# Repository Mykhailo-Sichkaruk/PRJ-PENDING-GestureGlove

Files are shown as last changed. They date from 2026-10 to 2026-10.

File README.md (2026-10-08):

# Gesture Glove — SMVIT 2026–2027

Team: **Mykhailo Sichkaruk (ST033)** and **[Yaroslav Marochok](https://github.com/ymarochok) (ST029)**.
Our goal is to complete the SMVIT semester project. The assigned team PRJ number is pending.
This is an independent repository created from the teacher's KNIFE/STHDF template.
GitHub: [PRJ-PENDING-GestureGlove](https://github.com/Mykhailo-Sichkaruk/PRJ-PENDING-GestureGlove).

## Start here

- [Team project and course structure](content/docs/sk/sthdf/PRJ-PENDING-GestureGlove/index.md)
- Individual work: [Mykhailo](content/docs/sk/sthdf/ST-033-SichkarukMykhailo/index.md), [Yaroslav](content/docs/sk/sthdf/ST-029-MarochokYaroslav/index.md)
- [Development setup, Arch graphics and MCP](docs/development.md)
- [Project decisions and AI handoff](docs/project-context.md)
- [Template provenance and submission questions](docs/template-provenance.md)
- [Original idea](hardware/reference/glove_smvit.pdf)
- [Existing CAD examples](examples/poc/README.md) — tooling PoCs, not validated device designs

## Development

Install Nix with flakes enabled. From this checkout:

```sh
nix develop
# Optional automatic shell entry, if direnv is installed and hooked into your shell:
direnv allow
```

Open the editable examples:

```sh
nix run .#freecad -- examples/poc/cad/glove-poc.FCStd
nix run .#eeschema -- examples/poc/electronics/glove/gesture-glove-v2.kicad_sch
nix run .#fritzing -- examples/poc/electronics/fritzing/gesture-glove.fzz
```

Documentation only (no CAD downloads):

```sh
nix develop .#docs
npm ci --prefix publishing/docusaurus
make build
make serve
```

Write course material in `content/docs/`; the copy under `publishing/docusaurus/docs/` is generated.
CI builds the site and saves an artifact; it does not publish or submit it to the teacher.
The inherited npm dependency lock currently reports audit findings; see [validation notes](docs/validation.md).

## Team workflow

Use a short feature branch, commit source files, and review through a pull request.
Yaroslav can clone the public repository now. Until collaborator access is granted, use a personal fork for pushes and open PRs from it.
Agree who edits a binary `.FCStd` or `.fzz` before starting: Git cannot reliably merge simultaneous edits.
Keep one person editing a KiCad sheet at a time; text-based storage does not guarantee a safe merge.
Record each student's contribution in their own ST section, with links to commits/results.
Keep course rosters, meeting access details, tokens, machine-specific settings and CAD caches in ignored `.local/`.

The toolchain targets x86_64 Linux on NixOS or another distribution with Nix.
Actual Arch GUI acceptance remains a teammate check; there is no dependency on Codex for manual development.

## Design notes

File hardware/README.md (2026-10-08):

# Hardware

`reference/glove_smvit.pdf` is the original project proposal.
`parts/fritzing/` contains reusable part bundles. Keep the Adafruit license with its part.
The current models live in `examples/poc/`. Final component selection, battery/power design,
pin allocation, enclosure dimensions and build verification are pending.

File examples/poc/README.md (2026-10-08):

# Archived tooling proof of concept

These are editable examples, not final course deliverables or fabrication files.

From the repository root:

```sh
nix run .#freecad -- examples/poc/cad/glove-poc.FCStd
nix run .#eeschema -- examples/poc/electronics/glove/gesture-glove-v2.kicad_sch
nix run .#fritzing -- examples/poc/electronics/fritzing/gesture-glove.fzz
```

The v2 KiCad schematic is the preferred electrical example. Original drafts remain here for reference.
Do not order a PCB or connect a battery from these conceptual examples.
Generators require an explicit `--replace-generated` option before overwriting examples.

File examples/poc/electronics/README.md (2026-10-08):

# Gesture glove — electrical prototype, revision 2

Open `glove/gesture-glove-v2.kicad_sch` for the circuit schematic, or
`fritzing/gesture-glove.fzz` in Fritzing's Breadboard view for the physical-looking
wiring diagram. The Fritzing parts and colored wires are separate editable
objects. Its background text is a separate annotation part.

## Read the drawings

- RF1–RF5: DIY resistive flex strips, drawn as variable resistors in KiCad.
- R1–R5: 10 kohm dividers to GND. C1–C5: 100 nF filters across those resistors.
- Each flex signal uses an ADC1-capable ESP32-S3 pin.
- U1: a finished Adafruit Feather ESP32-S3 #5323, with its charger/regulator.
  KiCad shows only the board connections used here. Pin numbers on this module
  symbol are logical interface names; it has no fabrication footprint.
- P1–P5 in Fritzing: one conductive fingertip pad each, with one electrical lead.
  SW1–SW5 in KiCad represent those pads touching the **same palm fabric**.
  They are not five purchased switches or permanently grounded fingertip pads.
- U2: GY-521 / MPU6050. VCC, GND, SCL, SDA and AD0 are connected; AD0 goes to
  GND for address 0x68. INT, XDA and XCL are unused and omitted in KiCad.
- SW6: a slide switch between EN and GND. Closing it disables the Feather
  regulator; it does not disconnect the battery or disable USB charging.
- BT1: a provisional 3.7 V, 500 mAh LiPo, wired to the board's battery socket.
  The external TP4056 listed in the original idea is superseded by the selected
  Feather's onboard charger in this PoC, not connected in parallel with it.

| Finger | Flex ADC / GPIO | Contact input / GPIO |
| --- | --- | --- |
| Thumb | A5 / 8 | A0 / 18 |
| Index | D5 / 5 | A1 / 17 |
| Middle | D6 / 6 | A2 / 16 |
| Ring | D9 / 9 | A3 / 15 |
| Little | D10 / 10 | A4 / 14 |

I2C: SDA = GPIO3, SCL = GPIO4. Enable internal input pull-ups for A0–A4;
contact with the grounded palm gives LOW. These are digital contact inputs,
not capacitive-touch inputs. Matching net labels in KiCad mean connected wires.
Crossing wires without a junction do not imply a connection.

## What is still provisional

This is a wiring proof of concept, not an electrically simulated or physically
tested device. DIY strip resistance and usable ADC range need measurement and
calibration. **GY-521 boards vary: confirm that the purchased variant works with
3.3 V at VCC before using this supply arrangement.** The exact battery lead
polarity and a suitable protected battery also need confirmation. Dimensions,
wire lengths, strain relief and mounting belong to the mechanical assembly.
The custom Fritzing part PCB views are illustrative; do not fabricate from them.

## Validation

`check_glove_connections.py` exports KiCad's netlist and compares its 16 nets
against Fritzing's native wire connections, including the Feather's internal
power/I2C buses. It checks that the five analog and five digital input nets,
power, I2C and EN connections agree. This catches pin-assignment errors that a
clean ERC alone would not catch. Fritzing's own application renders the supplied
breadboard SVG/PNG; KiCad exports the supplied schematic PDF.

## Sources and artwork

- [Original project idea](../glove_smvit.pdf).
- [Adafruit Feather ESP32-S3 pinouts](https://learn.adafruit.com/adafruit-esp32-s3-feather/pinouts).
- [Adafruit Feather board files and pinout PDF](https://github.com/adafruit/Adafruit-Feather-ESP32-S3-PCB).
- [Adafruit's Fritzing Feather part](https://github.com/adafruit/Fritzing-Library/blob/master/parts/Adafruit%20ESP32-S3%20Feather.fzpz),
  author `kattni`, dated 2022-04-12. Source Git blob:
  `1eed87918221c50f0c28b05f24bd90828101c212`.
  Its unmodified `.fzpz` and upstream license are in `fritzing/parts`.
  Generated sketches wrap the existing artwork in named SVG layer groups so
  Fritzing 1.0.6 displays it; geometry and connector IDs are preserved.
- GY-521 part: Fritzing's bundled `InvenSense_MPU6050.fzp`, author KingDarBoja.
- Flex strips, passive parts, pads, battery, switch and annotation graphics:
  simple custom parts generated by this project; indicative appearance/dimensions.
- [Fritzing MCP source](https://github.com/fedoragobrowse-design/fritzing-mcp).
- [Fritzing native part format](https://github.com/fritzing/fritzing-app/wiki/2.1-Part-file-format).
- [Codex project MCP configuration](https://learn.chatgpt.com/docs/extend/mcp).

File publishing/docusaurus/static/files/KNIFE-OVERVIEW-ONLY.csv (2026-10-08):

00.01.Navigations,,List of Knowledge Contributions – KNIFES,,,,,,,,,,,,,,,
,,,,,,,,,,,,,,,,,
ID,Category,Short Title,Status,Type,Priority,Description,Date of Record,"Context, Origin, Why it was initiated?",Technology,SFIA – Level,SFIA – Domain (?),SFIA – Maturity,Related KNIFE,Tags,Potential Outputs,Owner,Comment
K000001,,EA modelovanie a motivácia,hotové,Metodika / Nástroj,🎯,Systém motivácie pomocou lízaniek a spätnej väzby,01.03.2024,"Jedno z prvých TERNO, vzniklo pri návrhu systému motivácie v rámci tímu",,2,Business Analysis / Modelling,Diagrammatic,,,,,
K000002,Verzionanie-sdlc,Git workflow pre EA modely,v procese,Integrácia,🔥,"Multirelease stratégie, LemonTree, merge politiky",04.03.2024,Založené na reálnej potrebe riešiť multirelease workflow pre EA,,3,Configuration Management,Tool-based,,,,,
K000003,Platformy,LibreOffice + Python integrácia,v procese,Vývoj / Integrácia,🔥,Skriptovanie v LO cez Python a venv izolácie,08.03.2024,Reakcia na požiadavku na moderný vývoj v LibreOffice – Python/venv,,3,Software Development,Scriptable,,,,,
K000004,Technologie,Docker pre študentov (K12),plánované,Edukačné,🧠,Zjednodušené návody a obrázky pre začiatočníkov,20.03.2024,Vzniklo ako návrh edukačného materiálu pri tvorbe kurzov pre Docker,,2,DevOps / Infrastructure,Learning-based,,,,,
K000005,RiverOfMyLife,BaZi pre racionálne duše,zaradené,Osobný rozvoj / Algoritmika,💡,Sebapoznanie cez dátum a čas narodenia (BaZi),18.04.2025,Záznam vznikol počas diskusie o TCM a racionálnom prístupe k BaZi,,2,Knowledge Engineering,Exploratory,,,,,
K000006,,Tímová správa práv v Gitea,pripomenúť,Správa / Práva,📌,"Rozdelenie práv podľa tímov, chránené vetvy, PR politiky",08.04.2024,Zaznamenané počas diskusie o Gitea právach a workflow – T002,,3,Configuration Management,Tool-based,,,,,
K000007,,Helper skript na obrázky v Markdown,aktívne,Automatizácia,⚙️,Generovanie obrázkových blokov do .md vrátane URL,17.04.2024,Vzniklo pri návrhu Markdown workflow helpera – súvisiace s T007,,2,General Knowledge Work,Adaptive,,,,,
K000008,,DCMM a DAO – hodnota leadershipu,plánované,Hodnoty / Strategické,🧭,"Sebariadenie, dôvera a samočistiace systémy",04.04.2024,Diskusia o leadership kvalite v rámci strategických tém – T008,,2,Business Analysis / Modelling,Diagrammatic,,,,,
K000009,,LinkedIn post engine – AI automatizácia,koncept,Marketing / AI,🧪,Generovanie postov na LinkedIn z obsahu,10.04.2024,"Myšlienka z praxe na LinkedIn, súvis s T009 a zdieľaním obsahu",,2,General Knowledge Work,Adaptive,,,,,
K000010,,OpenAI klient – vlastná AI komunikácia,začiatok,Vývoj / AI,⚡,Appka s prepojením na OpenAI API a archív komunikácie,13.04.2024,"Začiatok vývoja AI nástroja, súvisí s plánom T018",,2,General Knowledge Work,Adaptive,,,,,
K000011,LO vývoj,Main.xba šablóna pre LO Basic,v backlogu,Šablóny / LO,🧱,Základná štartovacia knižnica makier v LibreOffice,09.04.2024,Téma makier v LibreOffice – samostatný štartovací modul,,2,General Knowledge Work,Adaptive,,,,,
K000012,,EA Workflow Add-In – pokročilé šablóny,v backlogu,EA Add-In,📂,Workflow pre pokročilých analytikov v EA,10.04.2024,Rozšírenie pre EA Add-In v rámci T012,,3,Configuration Management,Tool-based,,,,,
K000013,,ReadOnlyControl v EA – Workflow Add-In,koncept,EA Add-In,🔒,Obmedzenie práv v EA na základe kontextu a roly,10.04.2024,Doplnok k EA Add-In – konkrétne obmedzenia práv (ReadOnly),,3,Configuration Management,Tool-based,,,,,
K000014,,Manažér knižníc pre LO Basic,návrh,LibreOffice / Knižnice,📚,Načítanie a správa knižníc v LO Basic,10.04.2024,Nástroj pre správu LO knižníc – samostatne definovaný,,2,General Knowledge Work,Adaptive,,,,,
K000015,LO Vývoj,LibreOffice Basic → Python migrácia,aktívne,Migrácia / Vývoj,🔁,Konverzia VB makier do Python skriptov,13.04.2024,Migrácia z VB do Python – vzniklo počas T003 a T014,,3,Software Development,Scriptable,,,,,
K000016,,Helper skript pre LO symbolic link,v testovaní,Skriptovanie / LO,🧪,Obnova symbolic linku pre user/scripts/,13.04.2024,Podpora pre vývojové prostredie LO – vzniklo počas T015,,2,General Knowledge Work,Adaptive,,,,,
K000017,,AI-powered TERNO Planner,koncept,Plánovanie / AI,📅,Nástroj na správu a sledovanie TERNA záznamov,16.04.2025,Zaznamenané počas návrhu plánovania TERNA – prehľadový modul,,2,General Knowledge Work,Adaptive,,,,,
K000019,,"BaZi výpočty – algoritmus, hodiny, kalendár",zaradené,Algoritmika / Osobný rozvoj,🧠,"Výpočtový rámec BaZi v Pythone alebo Exceli, denné a hodinové analýzy, poradca",18.04.2025,Rozšírenie T005 – potreba výpočtu BaZi a hodinovej analýzy,,2,Knowledge Engineering,Exploratory,,,,,
K000020,LO Platforma pre komunitu,LibreOffice ako komunitná platforma,koncept,Strategické / Komunitné,🌍,"Podpora LO ako otvoreného, komunitného štandardu pre udržateľné riešenia",10.04.2025,Podpora LO ako komunitného nástroja v rámci T003,,3,Software Development,Scriptable,,,,,
K000021,,Princíp udržateľnosti v architektúre,koncept,Metodika / SDLC,🌱,Architektonické a dizajnové rozhodnutia s ohľadom na stabilitu a dlhodobosť,,Princíp objavený počas reflexie SDLC v T004 a T008,,2,General Knowledge Work,Adaptive,,,,,
K000022,,TERNO – terapeutické formy učenia,plánované,Edukačné / Kultúrne,🎭,"Satira, emócie a storytelling ako forma výuky a reflektovania reality",20.03.2025,Diskusia o forme učenia počas plánovania T004,,2,Learning Design,Teaching-oriented,,,,,
K000023,,AI interakcie – časová os a emócie,v návrhu,AI / UX / Sebapoznanie,🧭,"Zaznamenávanie malých interakcií, small-talkov a spätných väzieb pre orientáciu v čase",13.04.2025,Reflexia počas návrhu AI klienta – T018,,2,General Knowledge Work,Adaptive,,,,,
K000024,,OneNote ako zdroj metadát pre AI,v návrhu,Integrácia / Poznámky,🗃️,Prepájanie osobného poznámkového systému s AI klientom a projektmi,13.04.2025,Väzba medzi OneNote a projektovým manažmentom – T017,,2,General Knowledge Work,Adaptive,,,,,
K000025,,Kategorizácia TERNO podľa SDLC a 7D,zaradené,Metodika / Evidencia,📊,Zaradenie každého TERNO podľa fázy vývoja a vedomostnej disciplíny,01.03.2025,Systematizácia potreby klasifikovať TERNA – vzniklo pri tvorbe SSOT,,2,General Knowledge Work,Adaptive,,,,,
K000026,Framework / Edukačné,"KNIFE Framework pre vývoj a učenie sa (LibreOffice, Python)",v procese,Framework / Metodika / Edukačný základ,🔥,"Jednotný rámec pre budovanie, testovanie a učenie sa v malých krokoch pomocou LibreOffice + Python. Každý krok reprezentuje samostatnú jednotku (TERNO), ktorú je možné testovať a spätne dohľadať. Vhodné na výuku aj profesionálny vývoj.",20.04.2025,"Pri vývoji Personalised Calendards vznikla potreba vytvorič si „Dieľňu“ pre LO,Projekt 05-LibreOffice, priečinok 01-PersonalisedCalendars/01-Basic-Calendar/4/terno-framework","LibreOffice, Python, VS Code, Testovanie, JSON, Git",3,Software Development,Scriptable,,,,,
K000027,Versioning / Git,Git For Dummies – Central Concepts,v príprave,Edukačné / Praktické,🎯,"Jednoduché vysvetlenie Git základov pre začiatočníkov v GitEA (organizácia, repozitár, working directory, atď.)",28.04.2025,Vzniklo ako základný materiál pre školenie GitEA procesov a tímovú prácu,"Git, GitEA",2,Software Configuration,Learning-based,,,,,
K000028,CASO-CASA,"Context Aware System Ontology, Approach",v príprave,Metodika/Framework,,"Každé riešenie je o kontexte. Neexistuje jeden nástroj na vštky problémy. Toto zasahuje do filozofie.
Všetko je riadené spoločnými princípmy, dá sa učiť od starších disciplín a ušetriť čas. TRIZ, ",11.05.2025,"9.5. som sa opýtal na Orchideu, koľko má vlastne lupienkov….
Vznikol z toho koncept CASO, CASA, a ďalšie dialógy. O TRIZ … Epistemiologii …SFIA,",,"6,7","Enterprise and Business Architecture (STPL, ARCH) Information Strategy (ITSP) Innovation (INOV) Change Implementation (CIPM) Methods and Tools (METL) Organizational Capability Development (OCDV) ",Expert,#28-CASA,,,,
K000029,Platformy=OOODEV 4 LO,Prostredie vývojové python pre LO,riešené,Vývoj – Integrácia,🔥,"Profi prostredie pre pyhton dev v LO, OOODEV",16.05.2025,"Po nekonecnych konfiguraciach som poziadal GPT nech najde profi riesenie. Doporucil OOPDEV, tak to idem overit","LO, OOODEV","6,7",Software Development,Solution Architect,,,,,
K000030,GitHUB pages – Edu,Príbeh poznania SDLC,V riešení,Vzdelávanie-Marketing,🔥,"Pripravujem vzdelávacie kurzy, marketing cez LI, PT, YT, keby som priebezne zverejnoval svoju cestu, mal by som co pisať a bolo by to v kontexte KM, SDLC",17.05.2025,"Priprava FIIT, odchad z 365, potreba za zviditelnit a pripadne aj zarobit, dotiahnut projekty, produkty","GitHUB, EA, Python","Level 3 – Apply → samostatná práca
Level 5 – Ensure, Advise → zodpovednosť za kvalitu, konzultant
Llevel 6 – Initiate, Influence → strategická iniciatíva","KM (Knowledge Management), EDS (Education), ITMG (Information Technology Management)",Self learning, ,,,,
K000031,SDLC framework,„Document-as-Code“ framework,V riešení,Praktické používanie na výuku SDLC,🔥,"Tvorba dokumentov ako SDLC proces. Diplomovky, sprievodná dokumentácia pre zákazníklov, ….",18.05.2025,"Pri vytvaraní frameworku pre publikovanie na LI, PT, YT sme dosli k tomuto riešeniu na GITHUB ako Pages….","GITHyb, Pages, ","Level 4 – Enable (alebo L5 – Ensure, ak sa zavádza vo firme)","NOV, METL, DTAN, DESN, DOCU",3 – Defined (možno dorásť na 4 – Managed),"📘 SFIA vysvetlenie:
SFIA prvok
Význam v kontexte Document-as-Code
Level 4
Umožňuje štandardizované použitie vo výuke alebo týme
INOV
Inovácie pracovných postupov
METL
Metodiky vývoja a dokumentácie
DTAN
Digitálna analýza procesov a výstupov
DESN
Tvorba štruktúr obsahu (dizajn dokumentácie)
DOCU
Správa životného cyklu dokumentov a ich prepojení
",,,,
K000032,SDLC framework / Release management,„Enterprise Document-integrated SDLC“,V návrhu (alebo V riešení – podľa teba),"Firemné použitie, governance, traceability",🔥🔥,"Zavedenie Git-based dokumentačného frameworku pre prepojenie požiadaviek, rozhodnutí a architektúr naprieč SDLC vo firemnom prostredí s množstvom stakeholderov, JIRA taskov, externých dodávateľov a zložitým change manažmentom.",18.05.2025,"Zistenie, že dokumenty, ktoré ovplyvňujú produkt a organizáciu, musia byť verzované a auditovateľné ako kód. Git a Pages umožňujú prepojenie decision trailu s produktovými releasmi.","GitHub, Gitea, Pages, MkDocs, Mermaid, Git Actions",Level 5 – Ensure / Advise,"GOVN, METL, RELM, DESN, DOCU, SUBD, INOV",2–3 (Repeatable → Defined),,,,,
K000033,Smalltalk ako nástroj flow a kontextu,Smalltalk ako nástroj flowu a kontextu,V riešeni,Metodika / Psychológia práce / Kultúra tímu,🔥🔥,,20.05.2025,,,,,,,,,,
K000033,Psychológia práce / Kontext / Kultúra tímu,Smalltalk ako nástroj flowu a kontextu,Návrh (draft),Metodika,Stredná až vysoká,"Zber a reflexia neformálnych výrokov (smalltalkov) ako podpora tímovej pohody, flow a bezpečného kontextu.
Zber a štruktúrovaná reflexia neformálnych výrokov („smalltalkov“) v rámci dialógu s AI. Smalltalky fungujú ako mikrospúšťače pohody, humoru alebo hlbších vhľadov a podporujú kontextovú súdržnosť, flow atmosféru a psychologickú bezpečnosť",20.05.2025,"Vzniklo počas spolupráce Roman K. + GPT ako reakcia na potrebu zachytiť ľudský rozmer technických rozhovorov.
Vzniklo v rámci konverzácií s AI (Roman K.), ako reakcia na potrebu udržať „ľudskosť“ a kontinuitu medzi technickými a osobnými témami.","Markdown, GitHub, AI-dialogue, Prozaická kultúra",3–5,"People management, Knowledge sharing, Collaboration",Emerging,"K000002, K000010, K000015, K000021","smalltalk, flow, psychológia práce, humor, kultúra tímu","SMALLTALKs.md, článok, podcast, onboarding booklet",Roman K.,
K000036,Profesia Architekt urbanista na Slovensku,"Pracovno, finančný ekosystém",návrh,Ako na to?,Vysoká,"Absolventi architektúry už počas štúdia sú selektovaní  z komerčných ateliérov. Ponúkajú im brikády, prípadne dohody o vykonaní práce, za cenu nekvalifikovaných robotníkov.
Po skončení univerzity, sa študenti dostávajú do role živnostníkov, ale rozprávajú sa s nimi ako zo zamestnancami.
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

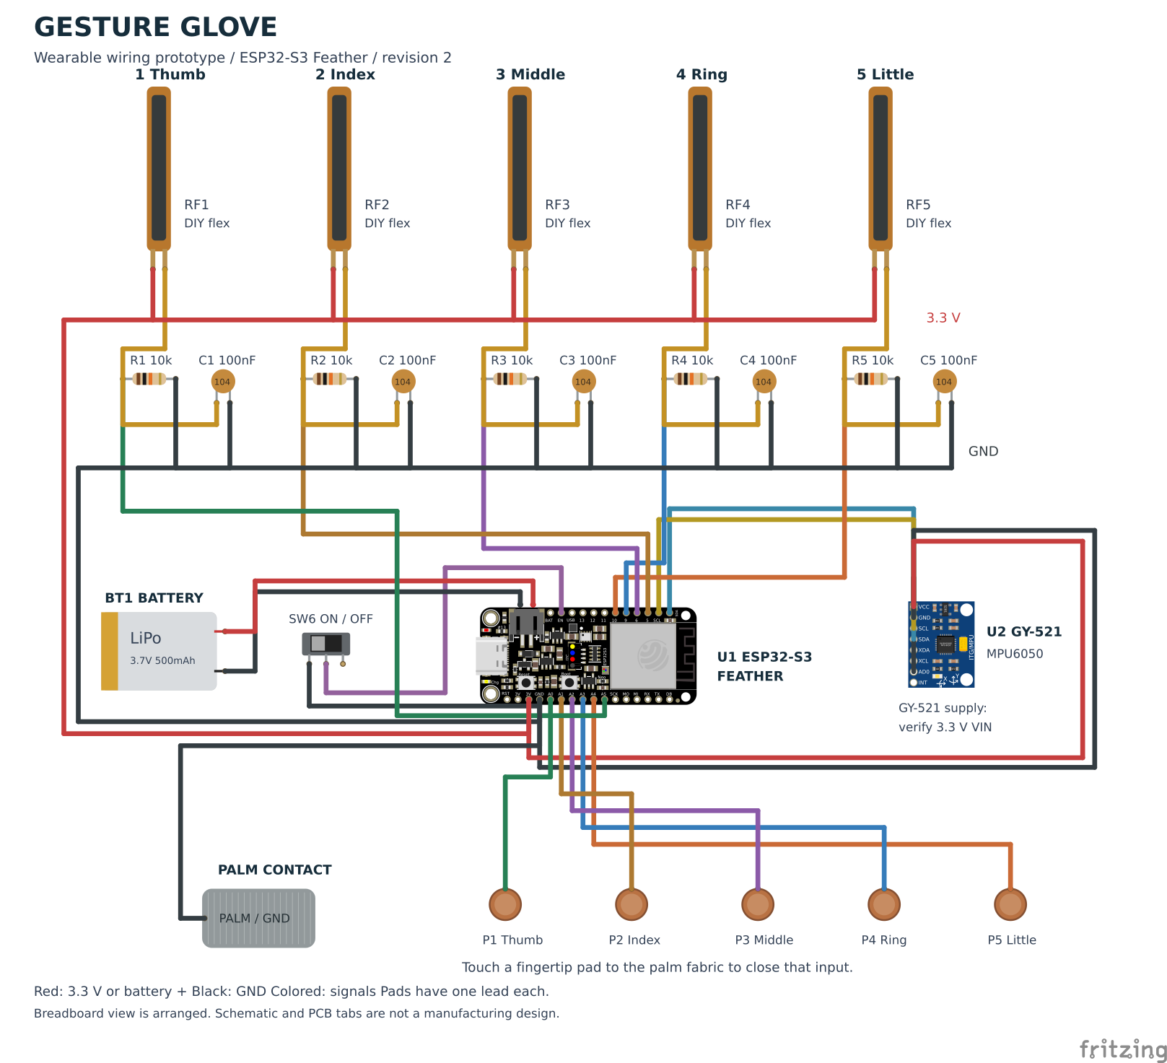
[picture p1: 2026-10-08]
examples/poc/electronics/fritzing/gesture-glove_breadboard.png

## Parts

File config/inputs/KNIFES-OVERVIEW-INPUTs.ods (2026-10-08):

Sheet: 04.List Of Knifes_20250928-1600
 | List of Knowledge Contributions – KNIFES |  |  |  |  |  |  |  |  |  |  |  |  |  |  |  |  |  |  |  |  | Stlpce pre automaticke generovanie md súborov
ID | display_id | GUID | DID | DAO | ShortTitle | Category | Type | Status | Priority | Date | Author | Authors | Tags | Description | Context | Origin | WhyItWasInitiated | Technology | SFIA_Level | SFIA_Domain | SFIA_Maturity | Related_KNIFE | PotentialOutputs | Owner | Org | Project | Locale | FolderName | SidebarLabel | LinkSlug | Copyright | RightsHolderContent | RightsHolderSystem | License | Disclaimer
ID | ShortTitle | Description | Status | Category | Type | Tags | Author | DisplayID | GUID | created | Priority | Context, Origin, Why it was initiated? | Technology | SFIA – Level | SFIA – Domain (?) | SFIA – Maturity | Related KNIFE | Potential Outputs | Owner | FolderName | SidebarLabel | LinkSlug
K001 | EA modelovanie a motivácia | Systém motivácie pomocou lízaniek a spätnej väzby | hotové | Methodology | Metodika / Nástroj |  | Roman Kazicka |  |  | 01.03.2024 | 🎯 | Jedno z prvých TERNO, vzniklo pri návrhu systému motivácie v rámci tímu |  | 2 | Business Analysis / Modelling | Diagrammatic
K002 | Git workflow pre EA modely | Multirelease stratégie, LemonTree, merge politiky | v procese | Verzionanie-sdlc | Integrácia |  | Roman Kazicka |  |  | 04.03.2024 | 🔥 | Založené na reálnej potrebe riešiť multirelease workflow pre EA |  | 3 | Configuration Management | Tool-based
K003 | LibreOffice + Python integrácia | Skriptovanie v LO cez Python a venv izolácie | v procese | Platformy | Vývoj / Integrácia |  | Roman Kazicka |  |  | 08.03.2024 | 🔥 | Reakcia na požiadavku na moderný vývoj v LibreOffice – Python/venv |  | 3 | Software Development | Scriptable
K004 | Docker pre študentov (K12) | Zjednodušené návody a obrázky pre začiatočníkov | plánované | Technologie | Edukačné |  | Roman Kazicka |  |  | 20.03.2024 | 🧠 | Vzniklo ako návrh edukačného materiálu pri tvorbe kurzov pre Docker |  | 2 | DevOps / Infrastructure | Learning-based
K005 | BaZi pre racionálne duše | Sebapoznanie cez dátum a čas narodenia (BaZi) | zaradené | RiverOfMyLife | Osobný rozvoj / Algoritmika |  | Roman Kazicka |  |  | 18.04.2025 | 💡 | Záznam vznikol počas diskusie o TCM a racionálnom prístupe k BaZi |  | 2 | Knowledge Engineering | Exploratory
K006 | Tímová správa práv v Gitea | Rozdelenie práv podľa tímov, chránené vetvy, PR politiky | pripomenúť | UserGuide | Správa Gitea / Práva |  | Roman Kazicka |  |  | 08.04.2024 | 📌 | Zaznamenané počas diskusie o Gitea právach a workflow – T002 |  | 3 | Configuration Management | Tool-based
K007 | Helper skript na obrázky v Markdown | Generovanie obrázkových blokov do .md vrátane URL | aktívne | UserGUide | Správa/Automatizácia |  | Roman Kazicka |  |  | 17.04.2024 | ⚙️ | Vzniklo pri návrhu Markdown workflow helpera – súvisiace s T007 |  | 2 | General Knowledge Work | Adaptive
K008 | DCMM a DAO – hodnota leadershipu | Sebariadenie, dôvera a samočistiace systémy | plánované | Leadership | Hodnoty / Strategické |  | Roman Kazicka |  |  | 04.04.2024 | 🧭 | Diskusia o leadership kvalite v rámci strategických tém – T008 |  | 2 | Business Analysis / Modelling | Diagrammatic
K009 | LinkedIn post engine – AI automatizácia | Generovanie postov na LinkedIn z obsahu | koncept | Marketing | Marketing / AI |  | Roman Kazicka |  |  | 10.04.2024 | 🧪 | Myšlienka z praxe na LinkedIn, súvis s T009 a zdieľaním obsahu |  | 2 | General Knowledge Work | Adaptive
K010 | OpenAI klient – vlastná AI komunikácia | Appka s prepojením na OpenAI API a archív komunikácie | začiatok | Products | Vývoj / AI |  | Roman Kazicka |  |  | 13.04.2024 | ⚡ | Začiatok vývoja AI nástroja, súvisí s plánom T018 |  | 2 | General Knowledge Work | Adaptive
K011 | Main.xba šablóna pre LO Basic | Základná štartovacia knižnica makier v LibreOffice | v backlogu | LO vývoj | Šablóny / LO |  | Roman Kazicka |  |  | 09.04.2024 | 🧱 | Téma makier v LibreOffice – samostatný štartovací modul |  | 2 | General Knowledge Work | Adaptive
K012 | EA Workflow Add-In – pokročilé šablóny | Workflow pre pokročilých analytikov v EA | v backlogu | ModelValidation | QualityOFModel/EA Add-In |  | Roman Kazicka |  |  | 10.04.2024 | 📂 | Rozšírenie pre EA Add-In v rámci T012 |  | 3 | Configuration Management | Tool-based
K013 | ReadOnlyControl v EA – Workflow Add-In | Obmedzenie práv v EA na základe kontextu a roly | koncept | ModelValidation | EA Add-In |  | Roman Kazicka |  |  | 10.04.2024 | 🔒 | Doplnok k EA Add-In – konkrétne obmedzenia práv (ReadOnly) |  | 3 | Configuration Management | Tool-based
K014 | Manažér knižníc pre LO Basic | Načítanie a správa knižníc v LO Basic | návrh | LO Development | LibreOffice / Knižnice |  | Roman Kazicka |  |  | 10.04.2024 | 📚 | Nástroj pre správu LO knižníc – samostatne definovaný |  | 2 | General Knowledge Work | Adaptive
K015 | LibreOffice Basic → Python migrácia | Konverzia VB makier do Python skriptov | aktívne | LO Vývoj | Migrácia / Vývoj |  | Roman Kazicka |  |  | 13.04.2024 | 🔁 | Migrácia z VB do Python – vzniklo počas T003 a T014 |  | 3 | Software Development | Scriptable
K016 | Helper skript pre LO symbolic link | Obnova symbolic linku pre user/scripts/ | v testovaní | LO Development | Skriptovanie / LO |  | Roman Kazicka |  |  | 13.04.2024 | 🧪 | Podpora pre vývojové prostredie LO – vzniklo počas T015 |  | 2 | General Knowledge Work | Adaptive
K017 | AI-powered TERNO Planner | Nástroj na správu a sledovanie TERNA záznamov | closed | Frameworks | Plánovanie / AI |  | Roman Kazicka |  |  | 16.04.2025 | 📅 | Zaznamenané počas návrhu plánovania TERNA – prehľadový modul |  | 2 | General Knowledge Work | Adaptive
K018 | KNIFE pre zvedavých | KNowledge In Friendle Examples“ | InProgress | Framework | UserGuide |  | Roman Kazička |  |  | 16.04.2025 | Hi | Každý systém potrebuje pekný návod. Pripravujem Active Presenter webinár, ale začiatok krátke súbory v GH | GitHub, | 7 | General Knowledge Work | Mentor
K019 | BaZi výpočty – algoritmus, hodiny, kalendár | Výpočtový rámec BaZi v Pythone alebo Exceli, denné a hodinové analýzy, poradca | zaradené | Development | Algoritmika / Osobný rozvoj |  | Roman Kazicka |  |  | 18.04.2025 | 🧠 | Rozšírenie T005 – potreba výpočtu BaZi a hodinovej analýzy |  | 2 | Knowledge Engineering | Exploratory
K020 | LibreOffice ako komunitná platforma | Podpora LO ako otvoreného, komunitného štandardu pre udržateľné riešenia | koncept | LO Platforma pre komunitu | Strategické / Komunitné |  | Roman Kazicka |  |  | 10.04.2025 | 🌍 | Podpora LO ako komunitného nástroja v rámci T003 |  | 3 | Software Development | Scriptable
K021 | Princíp udržateľnosti v architektúre | Architektonické a dizajnové rozhodnutia s ohľadom na stabilitu a dlhodobosť | koncept | Methodology | Metodika / SDLC |  | Roman Kazicka |  |  | 20.03.2025 | 🌱 | Princíp objavený počas reflexie SDLC v T004 a T008 |  | 2 | General Knowledge Work | Adaptive
K022 | TERNO – terapeutické formy učenia | Satira, emócie a storytelling ako forma výuky a reflektovania reality | plánované | EducationViaJoy | Edukačné / Kultúrne/Edukačný proces |  | Roman Kazicka |  |  | 20.03.2025 | 🎭 | Diskusia o forme učenia počas plánovania T004 |  | 2 | Learning Design | Teaching-oriented
K023 | AI interakcie – časová os a emócie | Zaznamenávanie malých interakcií, small-talkov a spätných väzieb pre orientáciu v čase | v návrhu | Smalltalks | AI / UX / Sebapoznanie |  | Roman Kazicka |  |  | 13.04.2025 | 🧭 | Reflexia počas návrhu AI klienta – T018 |  | 2 | General Knowledge Work | Adaptive
K024 | OneNote ako zdroj metadát pre AI | Prepájanie osobného poznámkového systému s AI klientom a projektmi | v návrhu | PersonalKMsystem | Integrácia / Poznámky |  | Roman Kazicka |  |  | 13.04.2025 | 🗃️ | Väzba medzi OneNote a projektovým manažmentom – T017 |  | 2 | General Knowledge Work | Adaptive
K025 | Kategorizácia TERNO podľa SDLC a 7D | Zaradenie každého TERNO podľa fázy vývoja a vedomostnej disciplíny | zaradené | Methodology | Metodika / Evidencia |  | Roman Kazicka |  |  | 01.03.2025 | 📊 | Systematizácia potreby klasifikovať TERNA – vzniklo pri tvorbe SSOT |  | 2 | General Knowledge Work | Adaptive
K026 | KNIFE Framework pre vývoj a učenie sa (LibreOffice, Python) | Jednotný rámec pre budovanie, testovanie a učenie sa v malých krokoch pomocou LibreOffice + Python. Každý krok reprezentuje samostatnú jednotku (TERNO), ktorú je možné testovať a spätne dohľadať. Vhodné na výuku aj profesionálny vývoj. | v procese | Framework / Edukačné | Framework / Metodika / Edukačný základ |  | Roman Kazicka |  |  | 20.04.2025 | 🔥 | Pri vývoji Personalised Calendards vznikla potreba vytvorič si „Dieľňu“ pre LO,Projekt 05-LibreOffice, priečinok 01-PersonalisedCalendars/01-Basic-Calendar/4/terno-framework | LibreOffice, Python, VS Code, Testovanie, JSON, Git | 3 | Software Development | Scriptable
K027 | Git For Dummies – Central Concepts | Jednoduché vysvetlenie Git základov pre začiatočníkov v GitEA (organizácia, repozitár, working directory, atď.) | v príprave | Versioning / Git | Edukačné / Praktické |  | Roman Kazicka |  |  | 28.04.2025 | 🎯 | Vzniklo ako základný materiál pre školenie GitEA procesov a tímovú prácu | Git, GitEA | 2 | Software Configuration | Learning-based
K028 | Context Aware System Ontology, Approach | Každé riešenie je o kontexte. Neexistuje jeden nástroj na vštky problémy. Toto zasahuje do filozofie. Všetko je riadené spoločnými princípmy, dá sa učiť od starších disciplín a ušetriť čas. TRIZ, | v príprave | CASO-CASA | Metodika/Framework |  | Roman Kazicka |  |  | 11.05.2025 |  | 9.5. som sa opýtal na Orchideu, koľko má vlastne lupienkov…. Vznikol z toho koncept CASO, CASA, a ďalšie dialógy. O TRIZ … Epistemiologii …SFIA, |  | 6,7 | Enterprise and Business Architecture (STPL, ARCH) Information Strategy (ITSP) Innovation (INOV) Change Implementation (CIPM) Methods and Tools (METL) Organizational Capability Development (OCDV) | Expert | #28-CASA
K029 | Prostredie vývojové python pre LO | Profi prostredie pre pyhton dev v LO, OOODEV | riešené | Platformy=OOODEV 4 LO | Vývoj – Integrácia |  | Roman Kazicka |  |  | 16.05.2025 | 🔥 | Po nekonecnych konfiguraciach som poziadal GPT nech najde profi riesenie. Doporucil OOPDEV, tak to idem overit | LO, OOODEV | 6,7 | Software Development | Solution Architect
K030 | Príbeh poznania SDLC | Pripravujem vzdelávacie kurzy, marketing cez LI, PT, YT, keby som priebezne zverejnoval svoju cestu, mal by som co pisať a bolo by to v kontexte KM, SDLC | V riešení | GitHUB pages – Edu | Vzdelávanie-Marketing |  | Roman Kazicka |  |  | 17.05.2025 | 🔥 | Priprava FIIT, odchad z 365, potreba za zviditelnit a pripadne aj zarobit, dotiahnut projekty, produkty | GitHUB, EA, Python | Level 3 – Apply → samostatná práca Level 5 – Ensure, Advise → zodpovednosť za kvalitu, konzultant Llevel 6 – Initiate, Influence → strategická iniciatíva | KM (Knowledge Management), EDS (Education), ITMG (Information Technology Management) | Self learning
K031 | „Document-as-Code“ framework | Tvorba dokumentov ako SDLC proces. Diplomovky, sprievodná dokumentácia pre zákazníklov, …. | V riešení | SDLC framework | Praktické používanie na výuku SDLC |  | Roman Kazicka |  |  | 18.05.2025 | 🔥 | Pri vytvaraní frameworku pre publikovanie na LI, PT, YT sme dosli k tomuto riešeniu na GITHUB ako Pages…. | GITHyb, Pages, | Level 4 – Enable (alebo L5 – Ensure, ak sa zavádza vo firme) | NOV, METL, DTAN, DESN, DOCU | 3 – Defined (možno dorásť na 4 – Managed) | 📘 SFIA vysvetlenie: SFIA prvok Význam v kontexte Document-as-Code Level 4 Umožňuje štandardizované použitie vo výuke alebo týme INOV Inovácie pracovných postupov METL Metodiky vývoja a dokumentácie DTAN Digitálna analýza procesov a výstupov DESN Tvorba štruktúr obsahu (dizajn dokumentácie) DOCU Správa životného cyklu dokumentov a ich prepojení
K032 | „Enterprise Document-integrated SDLC“ | Zavedenie Git-based dokumentačného frameworku pre prepojenie požiadaviek, rozhodnutí a architektúr naprieč SDLC vo firemnom prostredí s množstvom stakeholderov, JIRA taskov, externých dodávateľov a zložitým change manažmentom. | V návrhu (alebo V riešení – podľa teba) | SDLC framework / Release management | Firemné použitie, governance, traceability |  | Roman Kazicka |  |  | 18.05.2025 | 🔥🔥 | Zistenie, že dokumenty, ktoré ovplyvňujú produkt a organizáciu, musia byť verzované a auditovateľné ako kód. Git a Pages umožňujú prepojenie decision trailu s produktovými releasmi. | GitHub, Gitea, Pages, MkDocs, Mermaid, Git Actions | Level 5 – Ensure / Advise | GOVN, METL, RELM, DESN, DOCU, SUBD, INOV | 2–3 (Repeatable → Defined)
K033 | Smalltalk ako nástroj flowu a kontextu | Zber a reflexia neformálnych výrokov (smalltalkov) ako podpora tímovej pohody, flow a bezpečného kontextu. Zber a štruktúrovaná reflexia neformálnych výrokov („smalltalkov“) v rámci dialógu s AI. Smalltalky fungujú ako mikrospúšťače pohody, humoru alebo hlbších vhľadov a podporujú kontextovú súdržnosť, flow atmosféru a psychologickú bezpečnosť | Návrh (draft) | Psychológia práce / Kontext / Kultúra tímu | Metodika | smalltalk, flow, psychológia práce, humor, kultúra tímu | Roman Kazicka |  |  | 20.05.2025 | Stredná až vysoká | Vzniklo počas spolupráce Roman K. + GPT ako reakcia na potrebu zachytiť ľudský rozmer technických rozhovorov. Vzniklo v rámci konverzácií s AI (Roman K.), ako reakcia na potrebu udržať „ľudskosť“ a kontinuitu medzi technickými a osobnými témami. | Markdown, GitHub, AI-dialogue, Prozaická kultúra | 3–5 | People management, Knowledge sharing, Collaboration | Emerging | K002, K010, K015, K021 | SMALLTALKs.md, článok, podcast, onboarding booklet | Roman K.
K034 | Pracovno, finančný ekosystém | Absolventi architektúry už počas štúdia sú selektovaní z komerčných ateliérov. Ponúkajú im brikády, prípadne dohody o vykonaní práce, za cenu nekvalifikovaných robotníkov. Po skončení univerzity, sa študenti dostávajú do role živnostníkov, ale rozprávajú sa s nimi ako zo zamestnancami. Je potrebné mladým ľuďom jednoduchým jazykom vysvetliť kontext Slovenského práva, akými zákonmi sa riadi a ako si majú vybrať akou formou budú spolupracovať. | návrh | Profesia Architekt urbanista na Slovensku | Ako na to? | Pracovné právo | Roman Kazicka |  |  | 25.05.2025 | Vysoká | S dcérou, ktorá končí arhitektúru sa rozprávame o budúcnosti. Z rozhovorou cítim, že mladí architekti nemajú správne informácie a znalosti o právnom, ekonomickom a finančnom kontexte svojho statusu voči partnerom v branži. | Slovenské pracovno právne právo, obchodný zákonník, daňové zákony. | ? | ? | ? | ? | KNIFE na Githube | Roman K.
K035 | Context Aware Solutions / paradigma, solution |  | inprogress | CAS-ContextAwareSolutions |  |  | Roman Kazicka |  |  | 26.05.2025 | Vysoka | postupne, ako som si robil kazno ako bude cely ekosystem vyzerat, som prisiel na staru myslienku Kontext je klucovy…
K036 | Ako si vyrobit automaticke nastavovanie SSL | Pre FIIT PROLABORATE potrebujem SSL certifikaty, ako pre zakaznikov ako Dusan | finished | SSL certificates DIY | User guide |  | Roman Kazicka |  |  | 28.05.2025 | done | Pri obnovovani SSL certifkatov som zabijal kopec casu, teraz mam script
K037 | Sementicke a kontextove vyhladavanie nad GitHUB | Nestaci mat len data a informacie, je nevyhnutne ich spajat a dotazovat sa | Init | „Advanced GitHub KM Layer“ | Advance features |  | Roman Kazicka |  |  | 28.05.2025 | Middle | Pocas pripravy struktury CAS , KNIFE licencii, biznis modelu som dosiel na chybajucu vlastnost=kontextove vyhladavanie nad GITOM |  | a
K038 | Migracia Joomla -->GitHUB MkDocs | Zachovať históriu kurzu (2017–2025), udržať všetko v jednom hlavnom repozitári | Init | Publishing | Publishing |  | Roman Kazicka |  |  | 06.06.2025 | Middle | Pocas pripravy STH-SDLC 2025-2026 a pocas skumania GitHUB Sites, MkDocs som dospel k nazoru, ze by bolo suber premigrovat Migrácia učebných materiálov zo starého CMS (Joomla) do modernej dokumentačnej platformy | JOOMLA, GIRHUB, J2XML, J2MD
K039 | GitHUB Education Framework | Zastrešujúci rámec pre vzdelávacie kurzy na GitHube (GitHub Classroom, Pages, Docs generátory). Definuje zásady, šablóny, publishing flow a metriky.Skillmea, SEDUO maju vlastny framework , uvodny trailer, potom odskok do platenej verzie. To iste sa da aj na GitHUB. | init | Education Framework | Education Framework | Educations, Frameworks | Roman Kazicka |  |  | 10.06.2025 | Middle | Pri príprave STH2025–2026 sa ukázalo, že GitHub + Pages + generátory poskytujú kompletný, otvorený a bezplatný edukačný stack.Pocas pripravy STH2025-2026- som si uvedomil, ze GitHub, HitHUb Class, Sites, MkDOks umoznuju vytvorit cely ekosystem. A zadarmo. | GitHUB, Active Presenter |  | Learning-based / Methods & Tools |  |  | Framework | ROKA
K040 | SinglePageApplication – Webabased desktop app | GitHUb je zaklad aj pre vyvoj aplikacii nezavislych na koncovom zariadenie SPA Je to obrovsky priestor pre tvor bu vlastnych aplikacii ako KnowMyself | init | SPA-Framework | SPA framework | Solution Development, Framework | Roman Kazicka |  |  | 17.06.2025 | Low | Pocas pripravy webinara GitDos-Demo som si uvedomil, ze samotne nastroje pre dokumentovanie vyuzivaju VSC ako Web. Komplexne GUI ale na webe. | GitHUB, VUE, … |  |  |  |  | Framework | ROKA
K041 | Kontrola odpovedé študentov pomocou API na AI | Pre veľký počet študentov nie je možné kontrolovať odpovede na voľné otázky. AI by mohlo pomôcť. | in Progress | AI based training | AI in education |  | Roman Kazicka |  |  | 21.06.2026 | Middle | Počas prípravy repozitárov pre STH2025 riešim aj kontroly a komunikáciu so študentami. Je toho more, ale AI s API by bolo super. | API GPT
K042 | OneDrive backup to external disk on QNAP | This KNIFE explains how to create a full backup of your OneDrive data in cases where the local disk does not have sufficient capacity to mirror the entire cloud content. When 'Files On-Demand' is enabled, standard tools are unable to copy files – they can at best read their metadata. However, using tools like `rclone`, it becomes possible to back up the cloud directly without needing local mirroring. | inProgress | BACKUP | How To |  | Roman Kazicka |  |  | 27.07.2025 | TOP | Microsoft offers cloud storage up to several terabytes, but over time each storage fills up. At that point, you either have to buy more space or clean up existing data. I wanted neither. Since I had enough free capacity on an external disk connected to my QNAP NAS, I decided to create a complete copy of my OneDrive there. I had no idea it wouldn't be a trivial task. | rclone, Mac OS, QNAP
K043 | Základné informácie o ESG | Environment, Social, Government is crutial topic for human being survival. It is important to understand the background | Init | ESG- Krátky úvod | Education Explanantion |  | Roman Kazicka |  |  | 28.07.2025 | Low | I have attended mandatory training in 365 bank. Excellent lector, important topic. | Heart, Brain
K044 | Thunderbird – Archive-export | Omylom som poslal e-mail do archivu. Mam v poste asi 60GB udajov. Ako to riesit? | done md | UserGuide | HowTO |  | Roman Kazicka |  |  | 04.08.2025 | Low | Pri rutinnej práci som omylom poslal e-mail do archívu. Napadlo ma, že sa niečo nové naučím. Možno ušetrím diskovú kapacitu a nestratím možnosť vyhľadávať v histórii | Thunderbird | Intermediate | IT Communication | Basic | Thunderbird_Import_Helper.md 🔄
K045 | KNIFE047 – 7S Cycle of Meaningful Knowledge | Nové inšpirácie ohľadne riešenia aj z pohľadu marketingu | init | Inšpirácie | concepts, methodology |  | Roman Kazicka |  |  | 04.08.2025 | Low | KNIFE047_Reflexia_a_epistemologia.md, KNIFE047 – Epistemológia 4Curiosis |  |  | Social Communities
K046 | AI – Agent in OpenGPT |  | in progress | User Guide | HowTo |  | Roman Kazicka |  |  | 04.08.2025 | Low
K047 | KNIFE049 – Vyhľadávač nad OpenGPT históriou |  |  | UserGuide |  |  | Roman Kazicka |  |  | 04.08.2025 |  |  |  |  |  |  | KNIFE049_Vyhladavac.md
K048 | Open GPT, vytváranie prompt instructions | Vznizkli instrukcie pre zvedavych… | In progress | User Guide |  |  | Roman Kazicka |  |  | 04.08.2025
K049 | Google analytics – Fundamentals | Bez spňtnej väzby je všetko náročnejšie. GA4 poskytuje marketingové spätné väzby | new | Marketing | HowTo |  | Roman Kazicka |  |  | 04.08.2025 | Low
K050 | GitHub LMS Framework |  | new | Framework / Edukačné | Education Framework |  | Roman Kazicka |  |  | 04.08.2025 | duplicity K041
K051 | Framework for Project Management in GitHUB | Mám strašne veľa tém, veľa úloh, ako to manažovať, aby som sa neutopil v nesplnených úlohách, prípadne nezabudol na dôležité témy a neobjavoval ich znova a znova? | new | Framewok for Project Management | SDLC framework |  | Roman Kazicka |  |  | 10.08.2025 | low
K052 | Docusaurus Advanced Deployment Pipeline | Kontrola referencií v Docusaurus/MkDocs • DRY-run, strict a full link-check, detekcia chýb na začiatku procesu • Prevencia “nášľapných mín” pred buildom • Možnosť zaradiť ako QA krok do CI/CD | new | Best Practice | „Ako si nastaviť build a deploy tak, aby ťa chránil pred sebou samým.“ |  | Roman Kazicka |  |  | 10.08.2025
K053 | Ako obnoviť stav z minulosti? | Ako si obnoviť pokazné súbory? Ak mám v minulosti zachytené dobré údaje, nie je problém sa k nim vrátiť. stash, branch sandbox, práca mimo main • Obnova priečinkov alebo súborov z konkrétneho commitu • Praktické situácie, kedy to použiť, a ako sa vyhnúť strate dát | inprogress | Best Practice | Obnov mi dobré údaje |  | Roman Kazicka |  |  | 10.08.2025 | now
K054 | Central Panel for GIT – SDLC Git Management Makefile | • Jeden Makefile ako „single point of control“ • Všetky Git operácie, build/deploy, kontrola odkazov, sandbox, stash management • Prepojenie s princípom 3× merať, raz rezať • Možnosť adaptovať pre rôzne generátory HTML (Docusaurus, MkDocs, Hugo…) Podľa mňa by si to mohol v KNIFE_Overview zaradiť aj ako tematickú trojicu pod spoločný tag, napr. [KNIFE: Git-SDLC-Tools] alebo [KNIFE: Git-Advanced]. Tak sa to dá pekne použiť aj v kurze ako jedna lekcia s troma kapitolami – kontrola, obnova, centrálne riadenie. | done md | Best Practice | Správa súborov s git odporou |  | Roman Kazicka |  |  | 11.08.2025
K055 | AI Agent na monitoroavanie nákladov OpenGPT | Automatické reportovanie vstupných a výstupných tokenov.Presne tak – toto má perfektný predpoklad stať sa AI Agentom, ktorý: Vie čítať tvoje konverzácie z daného projektu. Vie ich prepojiť s tvojimi tagmi (napr. K055, Docusaurus, SDLC…) Vie spraviť sumár tokenov a nákladov za ľubovoľné obdobie. Vie urobiť porovnanie medzi projektmi (napr. “GitHub LMS” vs “KNIFE”). Vie urobiť ranking – najdrahší deň, téma, alebo dokonca konkrétny prompt. Takýto agent by si vedel zapnúť aj naprieč všetkými projektmi a raz za mesiac ti poslal “vyúčtovanie” + “Top 5 tém, ktoré pálili tokeny” + odhadovanú hodnotu v eurách. Ak chceš, môžem ti teraz: Urobiť retro-výpočet tokenov pre tento projekt (od začiatku). Pripraviť šablónu AIAgenta na token tracking, ktorú by si potom vedel spustiť v akomkoľvek projekte. | new | Management-Reporting | Reporting nad komunikáciou s OpenGPT formou AI Agenta |  | Roman Kazicka |  |  | 11.08.2025 | now | V jednom okamihu sa komunikácia zastavila na strane GPT stým, že má náročnú ulohu, ale že dnes to bude. Tak ma napadlo, koľko také „kecanie“ konzumuje tokenov. Super príprava pre vlastné API riešenia
K056 | AI Agent na monitoroavanie nákladov OpenGPT od počiatku komunikácie | Aká bola intenzita komunikácie od začiatku, koľko by to stálo cez API, Ktoré témy skonzumovali najviac energie? | new | Management-Reporting-from the Past | Reporting od začiatku komunikácie |  | Roman Kazicka |  |  | 11.08.2025 | now
K057 | STEM a Makerspace ako metodika vzdelávania | Spoljupracujem s Makerspace od roku 2016. POJEM STEM som priprodzene zahrnul do svojich metodík. Je vhodné to zviditeľniť v mojich aktivitách | New | Methodology | Systém pre vzdelávanie |  | Roman Kazicka |  |  | 24.08.2025 | now | Počas prípravy STHDF 2025-2025 so prišiel na to, že to mám zaradiť do osnov
K058 | Export Draw.io diagramu do A4 PNG | Ako pripraviť Drawio obázok aby sa vždy vmestil na A4 formát? | done md | User Guide | Ako na to? |  | Roman Kazicka |  |  | 24.08.2025 | done
K059 | Passkey ako bezpečnostný koncept | Ako funguje keypass? | new | Security concept | Explanation |  | Roman Kazicka |  |  | 24.08.2025
K060 | Docusaurus slugy a routing | Ako fungujú SLUGS v Docusaurus | new | Docusaurus Concept | Explanation |  | Roman Kazicka |  |  | 24.08.2025
K061 | Automatické generovanie KNIFES | Ako používať automatizáciu pri generovaní KNIFES | new | User Guide | User guide |  | Roman Kazicka |  |  | 24.08.2025
K062 | GA4, GTN, UTM | Ako funguje AG4, TGM a UTM? | new | Marketing | User Guides, principles |  | Roman Kazicka |  |  | 27.08.2025 | done | Marketig patrí medzi základné aktivity každého autora. Technici túto disciplínu podceňujú. Podľa metodikyu Q12 je to potrebné zabezpečeť, aby sme mali spätnú väzbu na naše aktivty z trhu.
K063 | MAKEFILE for KNIFE Ecosystem for Mac,Windows, Linux | Administrácia ecosystému KNIFE je pomerne komplexná úloha. Framework podporuje MacOS, Windows a Linux. MAKEFIEL umožňuje administráciu z jedného miesta. | New | Administration | GitHub Administration |  | Roman Kazicka |  |  | 31.08.2025 | now | Pri príprave treidy sa nabaľujú nové a nové podúlohy, ktoré musi byť splnené pred vyugenerovaním samotnej triedy zo šablény pre triedu. Táto šabl=ona by mala obsahovať všetky tieto vylepšenia
K064 | Porovnanie biznis plánov GitHub | Aká sú štartovacie náklady na profesionálny ekosystém v rámci GitHub? | New | SubscriptionPlans | Biznis plány GitHub-Prehľad |  | Roman Kazicka |  |  | 01.09.2025 | now | Počas prípravy na semster a získaní Edu Benefit ma zaujímali ceny za komenčné použitoe
K065 | GitHub Deployment stratégie | Deployment obsahu v GitHube sa dá vykonať viacerými spôsobmi. Obsah v MD súboroch sa dá konzumovať cez GitHub, cez Web Pages a Web Pages namapovať na vlastnú doménu. Tu je to popísané ako sa to robí | new | User Guide | Koncepty |  | Roman Kazicka |  |  | 02.09.2025 | now
K066 | Kruhový portrét v GIMP | Pri publikovaní na Web potrebujem kruhový formát obrázkov. Najjednoduchšie je použiť GIMP. Práca na 5 minút | new | User Guide | Návod |  | Roman Kazicka |  |  | 05.09.2025 | now
K067 | Kto ma pochváli, ak sa nepochválim sám? | Pre mnohých je ťažko písať o sebe. Ľahko sa skĺzne buď ku preceňovaniu, alebo naopak ku podceňovaniu. Je to ako s marketingom. Len predmetom propagácie sme my sami. Ak osa prezenetovať, pravdivo, transparentne? | new | Mentoring | Inšpirácie na hodnotový marketing seba samého |  | Roman Kazicka |  |  | 05.09.2025 | now | Pri každej aktualizácii CV, pri každej aktualizácií profilov mám otázky, čo a ko o sebe prezentovať. Viem, že nie som sám, a hľadanie odpovedí na moje otázky, môže pomôcť aj ďalším. |  |  |  |  | 7S Cycle of Meaningful Knowledge
K068 | EA Fundamentals | Enterprise architect (Sparxsystems technologies) je univerzálny modelovací nástroj. Od roku 2000 ho používam prakticky na dennej báze a pomáhal mi v každej roly, do ktorej som bol angažovaný. Technické roly, ale aj v Top managemente, ITSM, TOGAF, od konceptov, top level architektúry, solutiopn architektúry, analýzy, dizajnu, testovanie, v prevádzke. EA je veľmi komplexný, má bohatú dokumentáciu, napriek tomu je učiaca krivka náročná. Webinár ponúka prehľadnou formou úkážky v podobe praktických príkladov vlastnosti ause casy v ktorý je možné EA používať. | new | Knowledge sharing | Training on the praxis-praktický webinár ako začať pracovať s technológiou Enterprise Architect. Cca 6 hodinový webinár o základných nastaveniach EA 16+ |  | Roman Kazicka |  |  | 05.09.2025 | Sparxsystems | Dokumentácia v IT – strategická hodnota, alebop strata času https://leanpub.com/7D
K069 | 7Ds-Seven Disciplines for successful solutions | Metodika je zameraná na podporu aktivít v rámci SDLC. Každá potencálna iformácia má svoje miesto. A je úplne jedno v akej technológií sa implementuje. Ja som ju implementoval ako MDG do EA Sparxsystems, Do GitHUB, Rozpravcované je vo One Note | ongoing | Methodology | Metodika |  | Roman Kazicka |  |  | 05.09.2025 | medium | Túto metodiku používam asi 15 rokov. Pred 10 rokmi som o nej vydal aj knihu
K070 | APV-Assets-Perspectives-Views, Keep Your Aseests in Order | Metodika na podporu manažmentu aktív v rámci SDLC. TAXONÓMIA, ONTOLÓGIA aktív a ich vzťahiv z pohľadu rôznych rolí, aby platilo 3RS- Right – Information-For Right Role- In Right Time | ongoing | Methodology | Metodika |  | Roman Kazicka |  |  | 05.09.2025 | medium | Na tejto metodike pracujem minimálne od roku 2008. 8 Rokov som ju verifikoval v VW Bratislava na cca 50000 evidovaných aktívach IT. Je to nová veľá téma, bez ktorej IT nemôže napredovať, |  | LEVEL 6- expert | Enterprise architecture | Expert
K071 | Q12- Twelve quadrants for starting business | Metodika zameraná na 12 kvadrantov, ktoré je minimálne potrebné zohľadniť pri budovaní nového biznisu. Vhodné najmä pre startupy, ale aj pre každého jednotlivca, ktorý by chcel rozbehnúť vlastné podnikanie. | ongoing | Methodology | Metodika |  | Roman Kazicka |  |  | 05.09.2025 | medium | Túto metodiku som vypracoval pred 10 rokmi. Sám sa ňou nechávam inšpirovať, ale nie som dosť dôsledný. Plánujem to zmeniť. A aj keď nevyplňam jednotlivé kapitoly do nejakého systému, niekde v podvedmí sa riadim základnými princípmi. |  | Level 5 – Ensure / Advise | Biznis development | Beginner
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

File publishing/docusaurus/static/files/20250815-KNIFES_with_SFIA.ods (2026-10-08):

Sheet: 01.Document History
00.01.Navigations |  |  | Document History
 | # | Dátum zmeny | Autor zmeny | Popis zmeny | Stav
 | 1 | ?.04.2025 | Roman Kazicka | vytvorenie samostatného dokumentu pre evidenciu nápadov pre budúce aktivity, kurzy, projekty | in progress
 | 2 | 20.04.2025 | Roman Kazicka | Doplnenie stĺpcov | in progress
 | 3 | 20.04.2025 | OpenGPT | Vyplnenie SFIA parametrov | In progress
 | 4 | 20.04.2025 | OpenGPT | SFIA detaily do Purpose
 | 5 | 20.04.2025 | Roman Kazicka | Zmena nazvu TERNO na KNIFE # 🧠 KNIFE Framework for LibreOffice Python Development ## 🔪 What is KNIFE? **KNIFE** stands for: - **K**nowledge - **N**avigation - **I**nformation - **F**ramework - **E**xpertise
 | 6 | 27.07.2025 | Roman Kazicka | Upresnenie md suboru v GitHUBE Potrebujem viac stlpcov v md
 | 7
 | 8
 | 9
 | 10
 | 11
 | 12
 | 13
 | 14
 | 15
 | 16
 | 17
 | 18
 | 19
 | 20
 | 21
 | 22
 | 23
 | 24
 | 25
 | 26
 | 27
 | 28
 | 29
 | 30

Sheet: 04.List Of Knifes
00.01.Navigations |  | List of Knowledge Contributions – KNIFES |  |  |  |  |  |  |  |  |  |  |  |  |  |  |  |  | Stlpce pre automaticke generovanie md súborov
id | Category | title | Status | Type | Priority | Author | Description | created | Context, Origin, Why it was initiated? | Technology | SFIA – Level | SFIA – Domain (?) | SFIA – Maturity | Related KNIFE | Tags | Potential Outputs | Owner | Comment | FolderName | SidebarLabel | LinkSlug
K001 | Methodology | EA modelovanie a motivácia | hotové | Metodika / Nástroj | 🎯 | Roman Kazicka | Systém motivácie pomocou lízaniek a spätnej väzby | 01.03.2024 | Jedno z prvých TERNO, vzniklo pri návrhu systému motivácie v rámci tímu |  | 2 | Business Analysis / Modelling | Diagrammatic
K002 | Verzionanie-sdlc | Git workflow pre EA modely | v procese | Integrácia | 🔥 | Roman Kazicka | Multirelease stratégie, LemonTree, merge politiky | 04.03.2024 | Založené na reálnej potrebe riešiť multirelease workflow pre EA |  | 3 | Configuration Management | Tool-based
K003 | Platformy | LibreOffice + Python integrácia | v procese | Vývoj / Integrácia | 🔥 | Roman Kazicka | Skriptovanie v LO cez Python a venv izolácie | 08.03.2024 | Reakcia na požiadavku na moderný vývoj v LibreOffice – Python/venv |  | 3 | Software Development | Scriptable
K004 | Technologie | Docker pre študentov (K12) | plánované | Edukačné | 🧠 | Roman Kazicka | Zjednodušené návody a obrázky pre začiatočníkov | 20.03.2024 | Vzniklo ako návrh edukačného materiálu pri tvorbe kurzov pre Docker |  | 2 | DevOps / Infrastructure | Learning-based
K005 | RiverOfMyLife | BaZi pre racionálne duše | zaradené | Osobný rozvoj / Algoritmika | 💡 | Roman Kazicka | Sebapoznanie cez dátum a čas narodenia (BaZi) | 18.04.2025 | Záznam vznikol počas diskusie o TCM a racionálnom prístupe k BaZi |  | 2 | Knowledge Engineering | Exploratory
K006 | UserGuide | Tímová správa práv v Gitea | pripomenúť | Správa Gitea / Práva | 📌 | Roman Kazicka | Rozdelenie práv podľa tímov, chránené vetvy, PR politiky | 08.04.2024 | Zaznamenané počas diskusie o Gitea právach a workflow – T002 |  | 3 | Configuration Management | Tool-based
K007 | UserGUide | Helper skript na obrázky v Markdown | aktívne | Správa/Automatizácia | ⚙️ | Roman Kazicka | Generovanie obrázkových blokov do .md vrátane URL | 17.04.2024 | Vzniklo pri návrhu Markdown workflow helpera – súvisiace s T007 |  | 2 | General Knowledge Work | Adaptive
K008 | Leadership | DCMM a DAO – hodnota leadershipu | plánované | Hodnoty / Strategické | 🧭 | Roman Kazicka | Sebariadenie, dôvera a samočistiace systémy | 04.04.2024 | Diskusia o leadership kvalite v rámci strategických tém – T008 |  | 2 | Business Analysis / Modelling | Diagrammatic
K009 | Marketing | LinkedIn post engine – AI automatizácia | koncept | Marketing / AI | 🧪 | Roman Kazicka | Generovanie postov na LinkedIn z obsahu | 10.04.2024 | Myšlienka z praxe na LinkedIn, súvis s T009 a zdieľaním obsahu |  | 2 | General Knowledge Work | Adaptive
K010 | Products | OpenAI klient – vlastná AI komunikácia | začiatok | Vývoj / AI | ⚡ | Roman Kazicka | Appka s prepojením na OpenAI API a archív komunikácie | 13.04.2024 | Začiatok vývoja AI nástroja, súvisí s plánom T018 |  | 2 | General Knowledge Work | Adaptive
K011 | LO vývoj | Main.xba šablóna pre LO Basic | v backlogu | Šablóny / LO | 🧱 | Roman Kazicka | Základná štartovacia knižnica makier v LibreOffice | 09.04.2024 | Téma makier v LibreOffice – samostatný štartovací modul |  | 2 | General Knowledge Work | Adaptive
K012 | ModelValidation | EA Workflow Add-In – pokročilé šablóny | v backlogu | QualityOFModel/EA Add-In | 📂 | Roman Kazicka | Workflow pre pokročilých analytikov v EA | 10.04.2024 | Rozšírenie pre EA Add-In v rámci T012 |  | 3 | Configuration Management | Tool-based
K013 | ModelValidation | ReadOnlyControl v EA – Workflow Add-In | koncept | EA Add-In | 🔒 | Roman Kazicka | Obmedzenie práv v EA na základe kontextu a roly | 10.04.2024 | Doplnok k EA Add-In – konkrétne obmedzenia práv (ReadOnly) |  | 3 | Configuration Management | Tool-based
K014 | LO Development | Manažér knižníc pre LO Basic | návrh | LibreOffice / Knižnice | 📚 | Roman Kazicka | Načítanie a správa knižníc v LO Basic | 10.04.2024 | Nástroj pre správu LO knižníc – samostatne definovaný |  | 2 | General Knowledge Work | Adaptive
K015 | LO Vývoj | LibreOffice Basic → Python migrácia | aktívne | Migrácia / Vývoj | 🔁 | Roman Kazicka | Konverzia VB makier do Python skriptov | 13.04.2024 | Migrácia z VB do Python – vzniklo počas T003 a T014 |  | 3 | Software Development | Scriptable
K016 | LO Development | Helper skript pre LO symbolic link | v testovaní | Skriptovanie / LO | 🧪 | Roman Kazicka | Obnova symbolic linku pre user/scripts/ | 13.04.2024 | Podpora pre vývojové prostredie LO – vzniklo počas T015 |  | 2 | General Knowledge Work | Adaptive
K017 | Frameworks | AI-powered TERNO Planner | closed | Plánovanie / AI | 📅 | Roman Kazicka | Nástroj na správu a sledovanie TERNA záznamov | 16.04.2025 | Zaznamenané počas návrhu plánovania TERNA – prehľadový modul |  | 2 | General Knowledge Work | Adaptive
K019 | Development | BaZi výpočty – algoritmus, hodiny, kalendár | zaradené | Algoritmika / Osobný rozvoj | 🧠 | Roman Kazicka | Výpočtový rámec BaZi v Pythone alebo Exceli, denné a hodinové analýzy, poradca | 18.04.2025 | Rozšírenie T005 – potreba výpočtu BaZi a hodinovej analýzy |  | 2 | Knowledge Engineering | Exploratory
K020 | LO Platforma pre komunitu | LibreOffice ako komunitná platforma | koncept | Strategické / Komunitné | 🌍 | Roman Kazicka | Podpora LO ako otvoreného, komunitného štandardu pre udržateľné riešenia | 10.04.2025 | Podpora LO ako komunitného nástroja v rámci T003 |  | 3 | Software Development | Scriptable
K021 | Methodology | Princíp udržateľnosti v architektúre | koncept | Metodika / SDLC | 🌱 | Roman Kazicka | Architektonické a dizajnové rozhodnutia s ohľadom na stabilitu a dlhodobosť | 20.03.2025 | Princíp objavený počas reflexie SDLC v T004 a T008 |  | 2 | General Knowledge Work | Adaptive
K022 | EducationViaJoy | TERNO – terapeutické formy učenia | plánované | Edukačné / Kultúrne/Edukačný proces | 🎭 | Roman Kazicka | Satira, emócie a storytelling ako forma výuky a reflektovania reality | 20.03.2025 | Diskusia o forme učenia počas plánovania T004 |  | 2 | Learning Design | Teaching-oriented
K023 | Smalltalks | AI interakcie – časová os a emócie | v návrhu | AI / UX / Sebapoznanie | 🧭 | Roman Kazicka | Zaznamenávanie malých interakcií, small-talkov a spätných väzieb pre orientáciu v čase | 13.04.2025 | Reflexia počas návrhu AI klienta – T018 |  | 2 | General Knowledge Work | Adaptive
K024 | PersonalKMsystem | OneNote ako zdroj metadát pre AI | v návrhu | Integrácia / Poznámky | 🗃️ | Roman Kazicka | Prepájanie osobného poznámkového systému s AI klientom a projektmi | 13.04.2025 | Väzba medzi OneNote a projektovým manažmentom – T017 |  | 2 | General Knowledge Work | Adaptive
K025 | Methodology | Kategorizácia TERNO podľa SDLC a 7D | zaradené | Metodika / Evidencia | 📊 | Roman Kazicka | Zaradenie každého TERNO podľa fázy vývoja a vedomostnej disciplíny | 01.03.2025 | Systematizácia potreby klasifikovať TERNA – vzniklo pri tvorbe SSOT |  | 2 | General Knowledge Work | Adaptive
K026 | Framework / Edukačné | KNIFE Framework pre vývoj a učenie sa (LibreOffice, Python) | v procese | Framework / Metodika / Edukačný základ | 🔥 | Roman Kazicka | Jednotný rámec pre budovanie, testovanie a učenie sa v malých krokoch pomocou LibreOffice + Python. Každý krok reprezentuje samostatnú jednotku (TERNO), ktorú je možné testovať a spätne dohľadať. Vhodné na výuku aj profesionálny vývoj. | 20.04.2025 | Pri vývoji Personalised Calendards vznikla potreba vytvorič si „Dieľňu“ pre LO,Projekt 05-LibreOffice, priečinok 01-PersonalisedCalendars/01-Basic-Calendar/4/terno-framework | LibreOffice, Python, VS Code, Testovanie, JSON, Git | 3 | Software Development | Scriptable
K027 | Versioning / Git | Git For Dummies – Central Concepts | v príprave | Edukačné / Praktické | 🎯 | Roman Kazicka | Jednoduché vysvetlenie Git základov pre začiatočníkov v GitEA (organizácia, repozitár, working directory, atď.) | 28.04.2025 | Vzniklo ako základný materiál pre školenie GitEA procesov a tímovú prácu | Git, GitEA | 2 | Software Configuration | Learning-based
K028 | CASO-CASA | Context Aware System Ontology, Approach | v príprave | Metodika/Framework |  | Roman Kazicka | Každé riešenie je o kontexte. Neexistuje jeden nástroj na vštky problémy. Toto zasahuje do filozofie. Všetko je riadené spoločnými princípmy, dá sa učiť od starších disciplín a ušetriť čas. TRIZ, | 11.05.2025 | 9.5. som sa opýtal na Orchideu, koľko má vlastne lupienkov…. Vznikol z toho koncept CASO, CASA, a ďalšie dialógy. O TRIZ … Epistemiologii …SFIA, |  | 6,7 | Enterprise and Business Architecture (STPL, ARCH) Information Strategy (ITSP) Innovation (INOV) Change Implementation (CIPM) Methods and Tools (METL) Organizational Capability Development (OCDV) | Expert | #28-CASA
K029 | Platformy=OOODEV 4 LO | Prostredie vývojové python pre LO | riešené | Vývoj – Integrácia | 🔥 | Roman Kazicka | Profi prostredie pre pyhton dev v LO, OOODEV | 16.05.2025 | Po nekonecnych konfiguraciach som poziadal GPT nech najde profi riesenie. Doporucil OOPDEV, tak to idem overit | LO, OOODEV | 6,7 | Software Development | Solution Architect
K030 | GitHUB pages – Edu | Príbeh poznania SDLC | V riešení | Vzdelávanie-Marketing | 🔥 | Roman Kazicka | Pripravujem vzdelávacie kurzy, marketing cez LI, PT, YT, keby som priebezne zverejnoval svoju cestu, mal by som co pisať a bolo by to v kontexte KM, SDLC | 17.05.2025 | Priprava FIIT, odchad z 365, potreba za zviditelnit a pripadne aj zarobit, dotiahnut projekty, produkty | GitHUB, EA, Python | Level 3 – Apply → samostatná práca Level 5 – Ensure, Advise → zodpovednosť za kvalitu, konzultant Llevel 6 – Initiate, Influence → strategická iniciatíva | KM (Knowledge Management), EDS (Education), ITMG (Information Technology Management) | Self learning
K031 | SDLC framework | „Document-as-Code“ framework | V riešení | Praktické používanie na výuku SDLC | 🔥 | Roman Kazicka | Tvorba dokumentov ako SDLC proces. Diplomovky, sprievodná dokumentácia pre zákazníklov, …. | 18.05.2025 | Pri vytvaraní frameworku pre publikovanie na LI, PT, YT sme dosli k tomuto riešeniu na GITHUB ako Pages…. | GITHyb, Pages, | Level 4 – Enable (alebo L5 – Ensure, ak sa zavádza vo firme) | NOV, METL, DTAN, DESN, DOCU | 3 – Defined (možno dorásť na 4 – Managed) | 📘 SFIA vysvetlenie: SFIA prvok Význam v kontexte Document-as-Code Level 4 Umožňuje štandardizované použitie vo výuke alebo týme INOV Inovácie pracovných postupov METL Metodiky vývoja a dokumentácie DTAN Digitálna analýza procesov a výstupov DESN Tvorba štruktúr obsahu (dizajn dokumentácie) DOCU Správa životného cyklu dokumentov a ich prepojení
K032 | SDLC framework / Release management | „Enterprise Document-integrated SDLC“ | V návrhu (alebo V riešení – podľa teba) | Firemné použitie, governance, traceability | 🔥🔥 | Roman Kazicka | Zavedenie Git-based dokumentačného frameworku pre prepojenie požiadaviek, rozhodnutí a architektúr naprieč SDLC vo firemnom prostredí s množstvom stakeholderov, JIRA taskov, externých dodávateľov a zložitým change manažmentom. | 18.05.2025 | Zistenie, že dokumenty, ktoré ovplyvňujú produkt a organizáciu, musia byť verzované a auditovateľné ako kód. Git a Pages umožňujú prepojenie decision trailu s produktovými releasmi. | GitHub, Gitea, Pages, MkDocs, Mermaid, Git Actions | Level 5 – Ensure / Advise | GOVN, METL, RELM, DESN, DOCU, SUBD, INOV | 2–3 (Repeatable → Defined)
K033 | Smalltalk ako nástroj flow a kontextu | Smalltalk ako nástroj flowu a kontextu | V riešeni | Metodika / Psychológia práce / Kultúra tímu | 🔥🔥 | Roman Kazicka |  | 20.05.2025
K033 | Psychológia práce / Kontext / Kultúra tímu | Smalltalk ako nástroj flowu a kontextu | Návrh (draft) | Metodika | Stredná až vysoká | Roman Kazicka | Zber a reflexia neformálnych výrokov (smalltalkov) ako podpora tímovej pohody, flow a bezpečného kontextu. Zber a štruktúrovaná reflexia neformálnych výrokov („smalltalkov“) v rámci dialógu s AI. Smalltalky fungujú ako mikrospúšťače pohody, humoru alebo hlbších vhľadov a podporujú kontextovú súdržnosť, flow atmosféru a psychologickú bezpečnosť | 20.05.2025 | Vzniklo počas spolupráce Roman K. + GPT ako reakcia na potrebu zachytiť ľudský rozmer technických rozhovorov. Vzniklo v rámci konverzácií s AI (Roman K.), ako reakcia na potrebu udržať „ľudskosť“ a kontinuitu medzi technickými a osobnými témami. | Markdown, GitHub, AI-dialogue, Prozaická kultúra | 3–5 | People management, Knowledge sharing, Collaboration | Emerging | K002, K010, K015, K021 | smalltalk, flow, psychológia práce, humor, kultúra tímu | SMALLTALKs.md, článok, podcast, onboarding booklet | Roman K.
K036 | Profesia Architekt urbanista na Slovensku | Pracovno, finančný ekosystém | návrh | Ako na to? | Vysoká | Roman Kazicka | Absolventi architektúry už počas štúdia sú selektovaní z komerčných ateliérov. Ponúkajú im brikády, prípadne dohody o vykonaní práce, za cenu nekvalifikovaných robotníkov. Po skončení univerzity, sa študenti dostávajú do role živnostníkov, ale rozprávajú sa s nimi ako zo zamestnancami. Je potrebné mladým ľuďom jednoduchým jazykom vysvetliť kontext Slovenského práva, akými zákonmi sa riadi a ako si majú vybrať akou formou budú spolupracovať. | 25.05.2025 | S dcérou, ktorá končí arhitektúru sa rozprávame o budúcnosti. Z rozhovorou cítim, že mladí architekti nemajú správne informácie a znalosti o právnom, ekonomickom a finančnom kontexte svojho statusu voči partnerom v branži. | Slovenské pracovno právne právo, obchodný zákonník, daňové zákony. | ? | ? | ? | ? | Pracovné právo | KNIFE na Githube | Roman K.
K037 | CAS-ContextAwareSolutions | Context Aware Solutions / paradigma, solution | inprogress |  | Vysoka | Roman Kazicka |  | 26.05.2025 | postupne, ako som si robil kazno ako bude cely ekosystem vyzerat, som prisiel na staru myslienku Kontext je klucovy…
K038 | SSL certificates DIY | Ako si vyrobit automaticke nastavovanie SSL | finished | User guide | done | Roman Kazicka | Pre FIIT PROLABORATE potrebujem SSL certifikaty, ako pre zakaznikov ako Dusan | 28.05.2025 | Pri obnovovani SSL certifkatov som zabijal kopec casu, teraz mam script
K039 | „Advanced GitHub KM Layer“ | Sementicke a kontextove vyhladavanie nad GitHUB | Init | Advance features | Middle | Roman Kazicka | Nestaci mat len data a informacie, je nevyhnutne ich spajat a dotazovat sa | 28.05.2025 | Pocas pripravy struktury CAS , KNIFE licencii, biznis modelu som dosiel na chybajucu vlastnost=kontextove vyhladavanie nad GITOM |  | a
K040 | Publishing | Migracia Joomla -->GitHUB MkDocs | Init | Publishing | Middle | Roman Kazicka | Zachovať históriu kurzu (2017–2025), udržať všetko v jednom hlavnom repozitári | 06.06.2025 | Pocas pripravy STH-SDLC 2025-2026 a pocas skumania GitHUB Sites, MkDocs som dospel k nazoru, ze by bolo suber premigrovat Migrácia učebných materiálov zo starého CMS (Joomla) do modernej dokumentačnej platformy | JOOMLA, GIRHUB, J2XML, J2MD
K041 | Education Framework | GitHUB Education Framework | init | Education Framework | Middle | Roman Kazicka | Zastrešujúci rámec pre vzdelávacie kurzy na GitHube (GitHub Classroom, Pages, Docs generátory). Definuje zásady, šablóny, publishing flow a metriky.Skillmea, SEDUO maju vlastny framework , uvodny trailer, potom odskok do platenej verzie. To iste sa da aj na GitHUB. | 10.06.2025 | Pri príprave STH2025–2026 sa ukázalo, že GitHub + Pages + generátory poskytujú kompletný, otvorený a bezplatný edukačný stack.Pocas pripravy STH2025-2026- som si uvedomil, ze GitHub, HitHUb Class, Sites, MkDOks umoznuju vytvorit cely ekosystem. A zadarmo. | GitHUB, Active Presenter |  | Learning-based / Methods & Tools |  |  | Educations, Frameworks | Framework | ROKA
K042 | SPA-Framework | SinglePageApplication – Webabased desktop app | init | SPA framework | Low | Roman Kazicka | GitHUb je zaklad aj pre vyvoj aplikacii nezavislych na koncovom zariadenie SPA Je to obrovsky priestor pre tvor bu vlastnych aplikacii ako KnowMyself | 17.06.2025 | Pocas pripravy webinara GitDos-Demo som si uvedomil, ze samotne nastroje pre dokumentovanie vyuzivaju VSC ako Web. Komplexne GUI ale na webe. | GitHUB, VUE, … |  |  |  |  | Solution Development, Framework | Framework | ROKA
K043 | AI based training | Kontrola odpovedé študentov pomocou API na AI | in Progress | AI in education | Middle | Roman Kazicka | Pre veľký počet študentov nie je možné kontrolovať odpovede na voľné otázky. AI by mohlo pomôcť. | 21.06.2026 | Počas prípravy repozitárov pre STH2025 riešim aj kontroly a komunikáciu so študentami. Je toho more, ale AI s API by bolo super. | API GPT
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

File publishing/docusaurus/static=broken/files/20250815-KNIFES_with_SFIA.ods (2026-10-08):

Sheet: 01.Document History
00.01.Navigations |  |  | Document History
 | # | Dátum zmeny | Autor zmeny | Popis zmeny | Stav
 | 1 | ?.04.2025 | Roman Kazicka | vytvorenie samostatného dokumentu pre evidenciu nápadov pre budúce aktivity, kurzy, projekty | in progress
 | 2 | 20.04.2025 | Roman Kazicka | Doplnenie stĺpcov | in progress
 | 3 | 20.04.2025 | OpenGPT | Vyplnenie SFIA parametrov | In progress
 | 4 | 20.04.2025 | OpenGPT | SFIA detaily do Purpose
 | 5 | 20.04.2025 | Roman Kazicka | Zmena nazvu TERNO na KNIFE # 🧠 KNIFE Framework for LibreOffice Python Development ## 🔪 What is KNIFE? **KNIFE** stands for: - **K**nowledge - **N**avigation - **I**nformation - **F**ramework - **E**xpertise
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

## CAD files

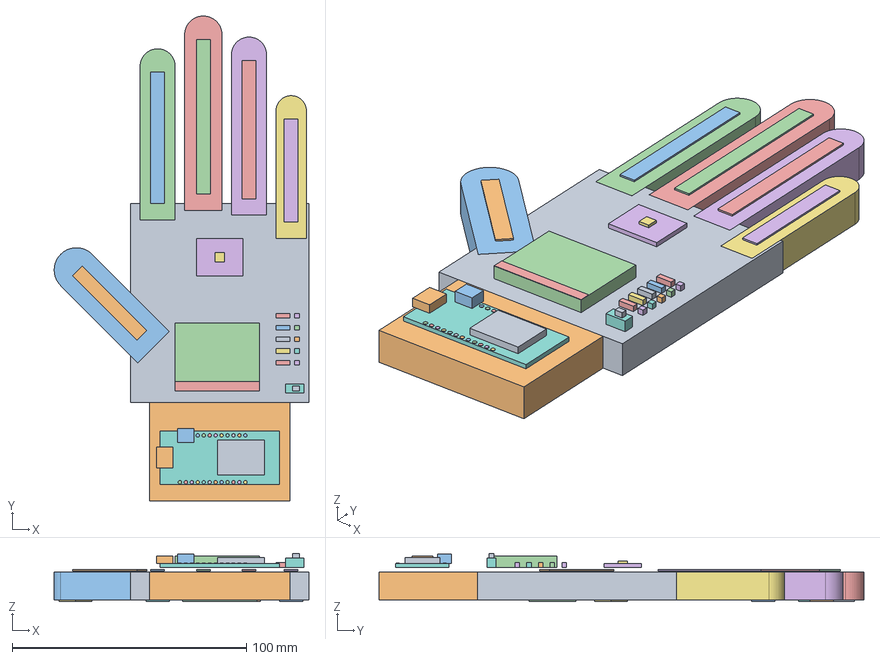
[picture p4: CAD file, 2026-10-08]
examples/poc/cad/glove-poc.FCStd
108.6 x 207.0 x 20.7 mm
Glove palm / back of hand
Wrist cuff
Thumb glove envelope
Index glove envelope
Middle glove envelope
Ring glove envelope
Little glove envelope
Adafruit ESP32-S3 Feather 5323 | PCB envelope
ESP32-S3 module | simplified
USB-C | charging and programming
JST-PH battery connector | simplified
Illustrative header pad (not a pin assignment)
Illustrative header pad (not a pin assignment)001
Illustrative header pad (not a pin assignment)002
Illustrative header pad (not a pin assignment)003
Illustrative header pad (not a pin assignment)004
Illustrative header pad (not a pin assignment)005
Illustrative header pad (not a pin assignment)006
Illustrative header pad (not a pin assignment)007
Illustrative header pad (not a pin assignment)008
Illustrative header pad (not a pin assignment)009
Illustrative header pad (not a pin assignment)010
Illustrative header pad (not a pin assignment)011
Illustrative header pad (not a pin assignment)012
Illustrative header pad (not a pin assignment)013
Illustrative header pad (not a pin assignment)014
Illustrative header pad (not a pin assignment)015
Illustrative header pad (not a pin assignment)016
Illustrative header pad (not a pin assignment)017
Illustrative header pad (not a pin assignment)018
Illustrative header pad (not a pin assignment)019
Illustrative header pad (not a pin assignment)020
Illustrative header pad (not a pin assignment)021
Illustrative header pad (not a pin assignment)022
Illustrative header pad (not a pin assignment)023
LiPo 3.7 V 500 mAh | Adafruit 1578
Battery end tape | illustrative
GY-521 / MPU6050 | provisional envelope
MPU6050 chip | simplified
Slide switch | proposed EN-to-GND control
Switch lever
Thumb | DIY flex strip
Index | DIY flex strip
Middle | DIY flex strip
Ring | DIY flex strip
Little | DIY flex strip
Thumb | contact pad on palm side
Index | contact pad on palm side
Middle | contact pad on palm side
Ring | contact pad on palm side
Little | contact pad on palm side
Common palm contact fabric | topology TBD
Flex 1 | 10 kohm resistor envelope
Flex 1 | 100 nF capacitor envelope
Flex 2 | 10 kohm resistor envelope
Flex 2 | 100 nF capacitor envelope
Flex 3 | 10 kohm resistor envelope
Flex 3 | 100 nF capacitor envelope
Flex 4 | 10 kohm resistor envelope
Flex 4 | 100 nF capacitor envelope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

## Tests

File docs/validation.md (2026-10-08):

# Migration validation — 2026-10-08

Verified on the original x86_64 NixOS host using the staged checkout at a different path:

- `nix flake check --no-build`: all outputs evaluate in pure mode.
- Built FreeCAD, KiCad, Fritzing and their MCP launchers with the pinned dependencies and graphics wrapper.
- `nix develop .#docs`: independent documentation toolchain; Node 22.23.3.
- `npm ci --prefix publishing/docusaurus` and `make build`: Slovak and English static sites build, including broken-link checks.
- All three CAD MCP servers initialize and list tools from both the checkout root and a nested directory: FreeCAD 17, KiCad 19, Fritzing 14 tools.
- FreeCAD GUI reopened the moved FCStd; RPC reported healthy and a rendered isometric screenshot showed the glove.
- KiCad GUI opened a disposable fixture; MCP created, read back and deleted a track. The first request arrived before KiCad was ready; retry after startup passed.
- Fritzing MCP searched parts, created/placed/wired/removed components, moved and restored a part in a copy, validated it and rendered SVG/PNG using native Fritzing.
- All 16 example KiCad/Fritzing nets still match.

The examples themselves were moved, not redesigned. These checks do not validate an electrical design or wearable safety.
Actual Arch Intel/NVIDIA GUI behavior remains to be checked by Yaroslav. The graphics bridge is configured, not claimed tested on his machine.

The teacher's original npm lockfile reports 81 audit findings (6 low, 16 moderate, 40 high, 19 critical) at installation time. It was preserved for this migration; no automatic breaking dependency upgrade was applied. Treat dependency updates as a separate follow-up before exposing a development server. Current CI produces static artifacts and does not publish a server.

The optional Teams wrapper is not part of these checks; university consent remains pending.

A clean Git clone at an unrelated `/tmp` path also passed pure flake evaluation, all six MCP initialization checks, the 16-net comparison and the complete Fritzing edit/render check. Its local Fritzing part cache was created from the committed part bundles.

After switching the workspace, Codex CLI confirmed the path-independent project MCP entries (Teams disabled), and direnv loaded Node/Python from the flake. GitHub Actions built and uploaded the site successfully on Ubuntu.

The optional NVIDIA branch initially failed because upstream nixGL still passed a removed `kernel` argument to nixpkgs' driver package. A small compatibility patch removes that obsolete argument. The patched wrapper built successfully against the host NVIDIA 595.71.05 driver; this is a build/launcher check, not an Arch rendering test.

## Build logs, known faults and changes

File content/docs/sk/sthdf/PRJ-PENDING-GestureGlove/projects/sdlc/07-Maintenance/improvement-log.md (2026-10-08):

---
# 🧩 Versioning – systém dopĺňa automaticky
fm_version: "1.0.1"

# Dátum buildu – generuje skript
fm_build: "2026-10-08T11:14:47.747967+00:00"

# Poznámka k verzii – voliteľné
fm_version_comment: ""

# 🆔 IDENTITY --------------------------------------------------------

# ID generuje CLI / skript

# Unikátne UUID – generuje skript
guid: "f34e710e-5ccc-4935-957f-16298ddcb8ea"

# 🧭 CONTEXT ---------------------------------------------------------

# DAO / doména (knife, sdlc, q12, 7ds...) dopĺňa skript
dao: "sthdf"

# Názov zápisu – dopĺňa používateľ
title: "improvement log"

# Krátky popis – dopĺňa používateľ (voliteľné)
description: "{{DESCRIPTION}}"

# 👥 AUTHORSHIP ------------------------------------------------------

# Hlavný autor – z globálneho configu
author: "Roman Kazicka"

# Zoznam autorov – generuje skript
authors:
  - "Roman Kazicka"

# 🗂 CLASSIFICATION ---------------------------------------------------

# Nadradená kategória – môže doplniť používateľ
category: ""

# Typ dokumentu (guide, case, tutorial...) – používateľ (voliteľné)
type: ""

# Priorita (low/medium/high) – voliteľné
priority: ""

# Tagy – odporúča sa 2–6 tagov.
# Typy tagov:
#   - rámce: knife, 7ds, sdlc, q12
#   - účel: tutorial, guide, pattern, case-study
#   - téma: git, backup, ai, communication
#   - úroveň: beginner, intermediate, advanced
tags: []

# 🌍 LOCALIZATION -----------------------------------------------------

# Jazyk dokumentu – doplní skript podľa štruktúry
locale: "sk"

# 🕒 LIFECYCLE --------------------------------------------------------

# Dátum vytvorenia – generuje skript
created: "2026-10-08 13:14"

# Dátum poslednej úpravy – dopĺňa človek
modified: "2026-10-08 13:14"

# Stav dokumentu – default "backlog"
status: "backlog"

# Viditeľnosť – default "public"
privacy: "public"

# ⚖ INTELLECTUAL PROPERTY -------------------------------------------

# Držiteľ práv k obsahu – dopĺňa skript
rights_holder_content: "Roman Kazicka"

# Systémový vlastník práv
rights_holder_system: "CAA / KNIFE / LetItGrow"

# Licencia
license: "CC-BY-NC-SA-4.0"

# Disclaimer
disclaimer: "Use at your own risk. Methods provided as-is; participation is voluntary and context-aware."

# Copyright
copyright: "© 2025 Roman Kazicka"

# 🔗 ORIGIN / PROVENANCE ---------------------------------------------

# Repozitár pôvodu
origin_repo: ""

# URL pôvodného repozitára
origin_repo_url: ""

# Commit pôvodu
origin_commit: ""

# Branch pôvodu
origin_branch: ""

# Systém pôvodu (CAA/KNIFE/STHDF…)
origin_system: "CAA"

# Pôvodný autor
origin_author: "Roman Kazicka"

# Importovaný zdroj
origin_imported_from: ""

# Dátum importu
origin_import_date: ""

# 🧱 RESERVED ---------------------------------------------------------

fm_reserved1: ""
fm_reserved2: ""
---

<!-- SDLC_INSTANCE_ID: PRJ-PENDING-GestureGlove -->

# 📒 Improvement Log

Zoznam drobných vylepšení a opráv vykonaných po nasadení.

---
**Navigation:** [⬆️ Up](./index.md) · [🏠 Home](../index.md)

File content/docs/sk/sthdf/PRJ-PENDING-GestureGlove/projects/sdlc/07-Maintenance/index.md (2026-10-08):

---
# 🧩 Versioning – systém dopĺňa automaticky
fm_version: "1.0.1"

# Dátum buildu – generuje skript
fm_build: "2026-10-08T11:14:47.747573+00:00"

# Poznámka k verzii – voliteľné
fm_version_comment: ""

# 🆔 IDENTITY --------------------------------------------------------

# ID generuje CLI / skript

# Unikátne UUID – generuje skript
guid: "e8df8b6d-9bee-461c-9f2f-52113b14c54b"

# 🧭 CONTEXT ---------------------------------------------------------

# DAO / doména (knife, sdlc, q12, 7ds...) dopĺňa skript
dao: "sthdf"

# Názov zápisu – dopĺňa používateľ
title: "07 Maintenance"

# Krátky popis – dopĺňa používateľ (voliteľné)
description: "{{DESCRIPTION}}"

# 👥 AUTHORSHIP ------------------------------------------------------

# Hlavný autor – z globálneho configu
author: "Roman Kazicka"

# Zoznam autorov – generuje skript
authors:
  - "Roman Kazicka"

# 🗂 CLASSIFICATION ---------------------------------------------------

# Nadradená kategória – môže doplniť používateľ
category: ""

# Typ dokumentu (guide, case, tutorial...) – používateľ (voliteľné)
type: ""

# Priorita (low/medium/high) – voliteľné
priority: ""

# Tagy – odporúča sa 2–6 tagov.
# Typy tagov:
#   - rámce: knife, 7ds, sdlc, q12
#   - účel: tutorial, guide, pattern, case-study
#   - téma: git, backup, ai, communication
#   - úroveň: beginner, intermediate, advanced
tags: []

# 🌍 LOCALIZATION -----------------------------------------------------

# Jazyk dokumentu – doplní skript podľa štruktúry
locale: "sk"

# 🕒 LIFECYCLE --------------------------------------------------------

# Dátum vytvorenia – generuje skript
created: "2026-10-08 13:14"

# Dátum poslednej úpravy – dopĺňa človek
modified: "2026-10-08 13:14"

# Stav dokumentu – default "backlog"
status: "backlog"

# Viditeľnosť – default "public"
privacy: "public"

# ⚖ INTELLECTUAL PROPERTY -------------------------------------------

# Držiteľ práv k obsahu – dopĺňa skript
rights_holder_content: "Roman Kazicka"

# Systémový vlastník práv
rights_holder_system: "CAA / KNIFE / LetItGrow"

# Licencia
license: "CC-BY-NC-SA-4.0"

# Disclaimer
disclaimer: "Use at your own risk. Methods provided as-is; participation is voluntary and context-aware."

# Copyright
copyright: "© 2025 Roman Kazicka"

# 🔗 ORIGIN / PROVENANCE ---------------------------------------------

# Repozitár pôvodu
origin_repo: ""

# URL pôvodného repozitára
origin_repo_url: ""

# Commit pôvodu
origin_commit: ""

# Branch pôvodu
origin_branch: ""

# Systém pôvodu (CAA/KNIFE/STHDF…)
origin_system: "CAA"

# Pôvodný autor
origin_author: "Roman Kazicka"

# Importovaný zdroj
origin_imported_from: ""

# Dátum importu
origin_import_date: ""

# 🧱 RESERVED ---------------------------------------------------------

fm_reserved1: ""
fm_reserved2: ""
---

<!-- SDLC_INSTANCE_ID: PRJ-PENDING-GestureGlove -->

# # 07 Maintenance

Údržba, drobné vylepšenia a plán aktualizácií.

---
**Navigation:** [⬆️ Up](../index.md) · [🏠 Home](../index.md)

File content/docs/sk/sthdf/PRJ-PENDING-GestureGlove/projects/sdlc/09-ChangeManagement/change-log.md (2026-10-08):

---
# 🧩 Versioning – systém dopĺňa automaticky
fm_version: "1.0.1"

# Dátum buildu – generuje skript
fm_build: "2026-10-08T11:14:47.758597+00:00"

# Poznámka k verzii – voliteľné
fm_version_comment: ""

# 🆔 IDENTITY --------------------------------------------------------

# ID generuje CLI / skript

# Unikátne UUID – generuje skript
guid: "8e195a03-16b6-4dfb-8f3f-9398da65a8c9"

# 🧭 CONTEXT ---------------------------------------------------------

# DAO / doména (knife, sdlc, q12, 7ds...) dopĺňa skript
dao: "sthdf"

# Názov zápisu – dopĺňa používateľ
title: "change log"

# Krátky popis – dopĺňa používateľ (voliteľné)
description: "{{DESCRIPTION}}"

# 👥 AUTHORSHIP ------------------------------------------------------

# Hlavný autor – z globálneho configu
author: "Roman Kazicka"

# Zoznam autorov – generuje skript
authors:
  - "Roman Kazicka"

# 🗂 CLASSIFICATION ---------------------------------------------------

# Nadradená kategória – môže doplniť používateľ
category: ""

# Typ dokumentu (guide, case, tutorial...) – používateľ (voliteľné)
type: ""

# Priorita (low/medium/high) – voliteľné
priority: ""

# Tagy – odporúča sa 2–6 tagov.
# Typy tagov:
#   - rámce: knife, 7ds, sdlc, q12
#   - účel: tutorial, guide, pattern, case-study
#   - téma: git, backup, ai, communication
#   - úroveň: beginner, intermediate, advanced
tags: []

# 🌍 LOCALIZATION -----------------------------------------------------

# Jazyk dokumentu – doplní skript podľa štruktúry
locale: "sk"

# 🕒 LIFECYCLE --------------------------------------------------------

# Dátum vytvorenia – generuje skript
created: "2026-10-08 13:14"

# Dátum poslednej úpravy – dopĺňa človek
modified: "2026-10-08 13:14"

# Stav dokumentu – default "backlog"
status: "backlog"

# Viditeľnosť – default "public"
privacy: "public"

# ⚖ INTELLECTUAL PROPERTY -------------------------------------------

# Držiteľ práv k obsahu – dopĺňa skript
rights_holder_content: "Roman Kazicka"

# Systémový vlastník práv
rights_holder_system: "CAA / KNIFE / LetItGrow"

# Licencia
license: "CC-BY-NC-SA-4.0"

# Disclaimer
disclaimer: "Use at your own risk. Methods provided as-is; participation is voluntary and context-aware."

# Copyright
copyright: "© 2025 Roman Kazicka"

# 🔗 ORIGIN / PROVENANCE ---------------------------------------------

# Repozitár pôvodu
origin_repo: ""

# URL pôvodného repozitára
origin_repo_url: ""

# Commit pôvodu
origin_commit: ""

# Branch pôvodu
origin_branch: ""

# Systém pôvodu (CAA/KNIFE/STHDF…)
origin_system: "CAA"

# Pôvodný autor
origin_author: "Roman Kazicka"

# Importovaný zdroj
origin_imported_from: ""

# Dátum importu
origin_import_date: ""

# 🧱 RESERVED ---------------------------------------------------------

fm_reserved1: ""
fm_reserved2: ""
---

<!-- SDLC_INSTANCE_ID: PRJ-PENDING-GestureGlove -->

# 📝 Change Log

Chronologický zoznam zmien (dátum, verzia, popis, autor).

---
**Navigation:** [⬆️ Up](./index.md) · [🏠 Home](../index.md)

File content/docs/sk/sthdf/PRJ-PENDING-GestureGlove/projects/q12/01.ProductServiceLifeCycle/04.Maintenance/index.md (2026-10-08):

---
# 🧩 Versioning – systém dopĺňa automaticky
fm_version: "1.0.1"

# Dátum buildu – generuje skript
fm_build: "2026-10-08T11:14:47.737770+00:00"

# Poznámka k verzii – voliteľné
fm_version_comment: ""

# 🆔 IDENTITY --------------------------------------------------------

# ID generuje CLI / skript

# Unikátne UUID – generuje skript
guid: "0da83c79-15aa-4abb-a5d5-c532cb7c4e25"

# 🧭 CONTEXT ---------------------------------------------------------

# DAO / doména (knife, sdlc, q12, 7ds...) dopĺňa skript
dao: "sthdf"

# Názov zápisu – dopĺňa používateľ
title: "04.Maintenance"

# Krátky popis – dopĺňa používateľ (voliteľné)
description: "{{DESCRIPTION}}"

# 👥 AUTHORSHIP ------------------------------------------------------

# Hlavný autor – z globálneho configu
author: "Roman Kazicka"

# Zoznam autorov – generuje skript
authors:
  - "Roman Kazicka"

# 🗂 CLASSIFICATION ---------------------------------------------------

# Nadradená kategória – môže doplniť používateľ
category: ""

# Typ dokumentu (guide, case, tutorial...) – používateľ (voliteľné)
type: ""

# Priorita (low/medium/high) – voliteľné
priority: ""

# Tagy – odporúča sa 2–6 tagov.
# Typy tagov:
#   - rámce: knife, 7ds, sdlc, q12
#   - účel: tutorial, guide, pattern, case-study
#   - téma: git, backup, ai, communication
#   - úroveň: beginner, intermediate, advanced
tags: []

# 🌍 LOCALIZATION -----------------------------------------------------

# Jazyk dokumentu – doplní skript podľa štruktúry
locale: "sk"

# 🕒 LIFECYCLE --------------------------------------------------------

# Dátum vytvorenia – generuje skript
created: "2026-10-08 13:14"

# Dátum poslednej úpravy – dopĺňa človek
modified: "2026-10-08 13:14"

# Stav dokumentu – default "backlog"
status: "backlog"

# Viditeľnosť – default "public"
privacy: "public"

# ⚖ INTELLECTUAL PROPERTY -------------------------------------------

# Držiteľ práv k obsahu – dopĺňa skript
rights_holder_content: "Roman Kazicka"

# Systémový vlastník práv
rights_holder_system: "CAA / KNIFE / LetItGrow"

# Licencia
license: "CC-BY-NC-SA-4.0"

# Disclaimer
disclaimer: "Use at your own risk. Methods provided as-is; participation is voluntary and context-aware."

# Copyright
copyright: "© 2025 Roman Kazicka"

# 🔗 ORIGIN / PROVENANCE ---------------------------------------------

# Repozitár pôvodu
origin_repo: ""

# URL pôvodného repozitára
origin_repo_url: ""

# Commit pôvodu
origin_commit: ""

# Branch pôvodu
origin_branch: ""

# Systém pôvodu (CAA/KNIFE/STHDF…)
origin_system: "CAA"

# Pôvodný autor
origin_author: "Roman Kazicka"

# Importovaný zdroj
origin_imported_from: ""

# Dátum importu
origin_import_date: ""

# 🧱 RESERVED ---------------------------------------------------------

fm_reserved1: ""
fm_reserved2: ""
---

<!-- SDLC_INSTANCE_ID: PRJ-PENDING-GestureGlove -->

# 04. Maintenance

Krátky opis účelu kapitoly (1–3 vety).

## Navigácia
- [↩️ Späť](../index.md)

## Vrstvy
- [01. Processes](./01.Processes/index.md)
- [02. Systems](./02.Systems/index.md)
- [03. Technologies](./03.Technologies/index.md)

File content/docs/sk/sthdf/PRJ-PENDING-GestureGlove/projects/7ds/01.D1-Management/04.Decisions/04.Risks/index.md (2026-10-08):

---
# 🧩 Versioning – systém dopĺňa automaticky
fm_version: "1.0.1"

# Dátum buildu – generuje skript
fm_build: "2026-10-08T11:14:47.727231+00:00"

# Poznámka k verzii – voliteľné
fm_version_comment: ""

# 🆔 IDENTITY --------------------------------------------------------

# ID generuje CLI / skript

# Unikátne UUID – generuje skript
guid: "d1838c22-599e-4a3c-a4e2-b9c0052855dd"

# 🧭 CONTEXT ---------------------------------------------------------

# DAO / doména (knife, sdlc, q12, 7ds...) dopĺňa skript
dao: "sthdf"

# Názov zápisu – dopĺňa používateľ
title: "04.Risks"

# Krátky popis – dopĺňa používateľ (voliteľné)
description: "{{DESCRIPTION}}"

# 👥 AUTHORSHIP ------------------------------------------------------

# Hlavný autor – z globálneho configu
author: "Roman Kazicka"

# Zoznam autorov – generuje skript
authors:
  - "Roman Kazicka"

# 🗂 CLASSIFICATION ---------------------------------------------------

# Nadradená kategória – môže doplniť používateľ
category: ""

# Typ dokumentu (guide, case, tutorial...) – používateľ (voliteľné)
type: ""

# Priorita (low/medium/high) – voliteľné
priority: ""

# Tagy – odporúča sa 2–6 tagov.
# Typy tagov:
#   - rámce: knife, 7ds, sdlc, q12
#   - účel: tutorial, guide, pattern, case-study
#   - téma: git, backup, ai, communication
#   - úroveň: beginner, intermediate, advanced
tags: []

# 🌍 LOCALIZATION -----------------------------------------------------

# Jazyk dokumentu – doplní skript podľa štruktúry
locale: "sk"

# 🕒 LIFECYCLE --------------------------------------------------------

# Dátum vytvorenia – generuje skript
created: "2026-10-08 13:14"

# Dátum poslednej úpravy – dopĺňa človek
modified: "2026-10-08 13:14"

# Stav dokumentu – default "backlog"
status: "backlog"

# Viditeľnosť – default "public"
privacy: "public"

# ⚖ INTELLECTUAL PROPERTY -------------------------------------------

# Držiteľ práv k obsahu – dopĺňa skript
rights_holder_content: "Roman Kazicka"

# Systémový vlastník práv
rights_holder_system: "CAA / KNIFE / LetItGrow"

# Licencia
license: "CC-BY-NC-SA-4.0"

# Disclaimer
disclaimer: "Use at your own risk. Methods provided as-is; participation is voluntary and context-aware."

# Copyright
copyright: "© 2025 Roman Kazicka"

# 🔗 ORIGIN / PROVENANCE ---------------------------------------------

# Repozitár pôvodu
origin_repo: ""

# URL pôvodného repozitára
origin_repo_url: ""

# Commit pôvodu
origin_commit: ""

# Branch pôvodu
origin_branch: ""

# Systém pôvodu (CAA/KNIFE/STHDF…)
origin_system: "CAA"

# Pôvodný autor
origin_author: "Roman Kazicka"

# Importovaný zdroj
origin_imported_from: ""

# Dátum importu
origin_import_date: ""

# 🧱 RESERVED ---------------------------------------------------------

fm_reserved1: ""
fm_reserved2: ""
---

<!-- SDLC_INSTANCE_ID: PRJ-PENDING-GestureGlove -->

# Risks

Sekcia **Risks** – vyplňte obsah podľa potreby.

---
**Navigation:** [⬆️ Up](../index.md) · [🏠 Home](../../../index.md)

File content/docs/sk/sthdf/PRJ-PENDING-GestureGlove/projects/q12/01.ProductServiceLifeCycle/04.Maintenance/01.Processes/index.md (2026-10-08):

---
# 🧩 Versioning – systém dopĺňa automaticky
fm_version: "1.0.1"

# Dátum buildu – generuje skript
fm_build: "2026-10-08T11:14:47.746556+00:00"

# Poznámka k verzii – voliteľné
fm_version_comment: ""

# 🆔 IDENTITY --------------------------------------------------------

# ID generuje CLI / skript

# Unikátne UUID – generuje skript
guid: "41dcb033-a1ea-42bb-a1fa-474d77cbda6d"

# 🧭 CONTEXT ---------------------------------------------------------

# DAO / doména (knife, sdlc, q12, 7ds...) dopĺňa skript
dao: "sthdf"

# Názov zápisu – dopĺňa používateľ
title: "01.Processes"

# Krátky popis – dopĺňa používateľ (voliteľné)
description: "{{DESCRIPTION}}"

# 👥 AUTHORSHIP ------------------------------------------------------

# Hlavný autor – z globálneho configu
author: "Roman Kazicka"

# Zoznam autorov – generuje skript
authors:
  - "Roman Kazicka"

# 🗂 CLASSIFICATION ---------------------------------------------------

# Nadradená kategória – môže doplniť používateľ
category: ""

# Typ dokumentu (guide, case, tutorial...) – používateľ (voliteľné)
type: ""

# Priorita (low/medium/high) – voliteľné
priority: ""

# Tagy – odporúča sa 2–6 tagov.
# Typy tagov:
#   - rámce: knife, 7ds, sdlc, q12
#   - účel: tutorial, guide, pattern, case-study
#   - téma: git, backup, ai, communication
#   - úroveň: beginner, intermediate, advanced
tags: []

# 🌍 LOCALIZATION -----------------------------------------------------

# Jazyk dokumentu – doplní skript podľa štruktúry
locale: "sk"

# 🕒 LIFECYCLE --------------------------------------------------------

# Dátum vytvorenia – generuje skript
created: "2026-10-08 13:14"

# Dátum poslednej úpravy – dopĺňa človek
modified: "2026-10-08 13:14"

# Stav dokumentu – default "backlog"
status: "backlog"

# Viditeľnosť – default "public"
privacy: "public"

# ⚖ INTELLECTUAL PROPERTY -------------------------------------------

# Držiteľ práv k obsahu – dopĺňa skript
rights_holder_content: "Roman Kazicka"

# Systémový vlastník práv
rights_holder_system: "CAA / KNIFE / LetItGrow"

# Licencia
license: "CC-BY-NC-SA-4.0"

# Disclaimer
disclaimer: "Use at your own risk. Methods provided as-is; participation is voluntary and context-aware."

# Copyright
copyright: "© 2025 Roman Kazicka"

# 🔗 ORIGIN / PROVENANCE ---------------------------------------------

# Repozitár pôvodu
origin_repo: ""

# URL pôvodného repozitára
origin_repo_url: ""

# Commit pôvodu
origin_commit: ""

# Branch pôvodu
origin_branch: ""

# Systém pôvodu (CAA/KNIFE/STHDF…)
origin_system: "CAA"

# Pôvodný autor
origin_author: "Roman Kazicka"

# Importovaný zdroj
origin_imported_from: ""

# Dátum importu
origin_import_date: ""

# 🧱 RESERVED ---------------------------------------------------------

fm_reserved1: ""
fm_reserved2: ""
---

<!-- SDLC_INSTANCE_ID: PRJ-PENDING-GestureGlove -->

# 01. Processes

Zoznam procesov / postupov súvisiacich s touto oblasťou.

- Proces A
- Proces B

[↩️ Späť](../index.md)

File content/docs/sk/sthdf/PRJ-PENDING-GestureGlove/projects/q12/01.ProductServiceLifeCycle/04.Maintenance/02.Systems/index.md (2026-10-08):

---
# 🧩 Versioning – systém dopĺňa automaticky
fm_version: "1.0.1"

# Dátum buildu – generuje skript
fm_build: "2026-10-08T11:14:47.746065+00:00"

# Poznámka k verzii – voliteľné
fm_version_comment: ""

# 🆔 IDENTITY --------------------------------------------------------

# ID generuje CLI / skript

# Unikátne UUID – generuje skript
guid: "4caf7d62-4e0e-4d44-8a57-875de74b6a48"

# 🧭 CONTEXT ---------------------------------------------------------

# DAO / doména (knife, sdlc, q12, 7ds...) dopĺňa skript
dao: "sthdf"

# Názov zápisu – dopĺňa používateľ
title: "02.Systems"

# Krátky popis – dopĺňa používateľ (voliteľné)
description: "{{DESCRIPTION}}"

# 👥 AUTHORSHIP ------------------------------------------------------

# Hlavný autor – z globálneho configu
author: "Roman Kazicka"

# Zoznam autorov – generuje skript
authors:
  - "Roman Kazicka"

# 🗂 CLASSIFICATION ---------------------------------------------------

# Nadradená kategória – môže doplniť používateľ
category: ""

# Typ dokumentu (guide, case, tutorial...) – používateľ (voliteľné)
type: ""

# Priorita (low/medium/high) – voliteľné
priority: ""

# Tagy – odporúča sa 2–6 tagov.
# Typy tagov:
#   - rámce: knife, 7ds, sdlc, q12
#   - účel: tutorial, guide, pattern, case-study
#   - téma: git, backup, ai, communication
#   - úroveň: beginner, intermediate, advanced
tags: []

# 🌍 LOCALIZATION -----------------------------------------------------

# Jazyk dokumentu – doplní skript podľa štruktúry
locale: "sk"

# 🕒 LIFECYCLE --------------------------------------------------------

# Dátum vytvorenia – generuje skript
created: "2026-10-08 13:14"

# Dátum poslednej úpravy – dopĺňa človek
modified: "2026-10-08 13:14"

# Stav dokumentu – default "backlog"
status: "backlog"

# Viditeľnosť – default "public"
privacy: "public"

# ⚖ INTELLECTUAL PROPERTY -------------------------------------------

# Držiteľ práv k obsahu – dopĺňa skript
rights_holder_content: "Roman Kazicka"

# Systémový vlastník práv
rights_holder_system: "CAA / KNIFE / LetItGrow"

# Licencia
license: "CC-BY-NC-SA-4.0"

# Disclaimer
disclaimer: "Use at your own risk. Methods provided as-is; participation is voluntary and context-aware."

# Copyright
copyright: "© 2025 Roman Kazicka"

# 🔗 ORIGIN / PROVENANCE ---------------------------------------------

# Repozitár pôvodu
origin_repo: ""

# URL pôvodného repozitára
origin_repo_url: ""

# Commit pôvodu
origin_commit: ""

# Branch pôvodu
origin_branch: ""

# Systém pôvodu (CAA/KNIFE/STHDF…)
origin_system: "CAA"

# Pôvodný autor
origin_author: "Roman Kazicka"

# Importovaný zdroj
origin_imported_from: ""

# Dátum importu
origin_import_date: ""

# 🧱 RESERVED ---------------------------------------------------------

fm_reserved1: ""
fm_reserved2: ""
---

<!-- SDLC_INSTANCE_ID: PRJ-PENDING-GestureGlove -->

# 02. Systems

Prehľad systémov / nástrojov podporujúcich túto oblasť.

- Systém X
- Systém Y

[↩️ Späť](../index.md)

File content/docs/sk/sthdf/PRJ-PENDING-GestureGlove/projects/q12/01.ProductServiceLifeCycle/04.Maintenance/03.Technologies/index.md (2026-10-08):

---
# 🧩 Versioning – systém dopĺňa automaticky
fm_version: "1.0.1"

# Dátum buildu – generuje skript
fm_build: "2026-10-08T11:14:47.747085+00:00"

# Poznámka k verzii – voliteľné
fm_version_comment: ""

# 🆔 IDENTITY --------------------------------------------------------

# ID generuje CLI / skript

# Unikátne UUID – generuje skript
guid: "3fe244a7-121d-482e-a5a8-998a2ca347a7"

# 🧭 CONTEXT ---------------------------------------------------------

# DAO / doména (knife, sdlc, q12, 7ds...) dopĺňa skript
dao: "sthdf"

# Názov zápisu – dopĺňa používateľ
title: "03.Technologies"

# Krátky popis – dopĺňa používateľ (voliteľné)
description: "{{DESCRIPTION}}"

# 👥 AUTHORSHIP ------------------------------------------------------

# Hlavný autor – z globálneho configu
author: "Roman Kazicka"

# Zoznam autorov – generuje skript
authors:
  - "Roman Kazicka"

# 🗂 CLASSIFICATION ---------------------------------------------------

# Nadradená kategória – môže doplniť používateľ
category: ""

# Typ dokumentu (guide, case, tutorial...) – používateľ (voliteľné)
type: ""

# Priorita (low/medium/high) – voliteľné
priority: ""

# Tagy – odporúča sa 2–6 tagov.
# Typy tagov:
#   - rámce: knife, 7ds, sdlc, q12
#   - účel: tutorial, guide, pattern, case-study
#   - téma: git, backup, ai, communication
#   - úroveň: beginner, intermediate, advanced
tags: []

# 🌍 LOCALIZATION -----------------------------------------------------

# Jazyk dokumentu – doplní skript podľa štruktúry
locale: "sk"

# 🕒 LIFECYCLE --------------------------------------------------------

# Dátum vytvorenia – generuje skript
created: "2026-10-08 13:14"

# Dátum poslednej úpravy – dopĺňa človek
modified: "2026-10-08 13:14"

# Stav dokumentu – default "backlog"
status: "backlog"

# Viditeľnosť – default "public"
privacy: "public"

# ⚖ INTELLECTUAL PROPERTY -------------------------------------------

# Držiteľ práv k obsahu – dopĺňa skript
rights_holder_content: "Roman Kazicka"

# Systémový vlastník práv
rights_holder_system: "CAA / KNIFE / LetItGrow"

# Licencia
license: "CC-BY-NC-SA-4.0"

# Disclaimer
disclaimer: "Use at your own risk. Methods provided as-is; participation is voluntary and context-aware."

# Copyright
copyright: "© 2025 Roman Kazicka"

# 🔗 ORIGIN / PROVENANCE ---------------------------------------------

# Repozitár pôvodu
origin_repo: ""

# URL pôvodného repozitára
origin_repo_url: ""

# Commit pôvodu
origin_commit: ""

# Branch pôvodu
origin_branch: ""

# Systém pôvodu (CAA/KNIFE/STHDF…)
origin_system: "CAA"

# Pôvodný autor
origin_author: "Roman Kazicka"

# Importovaný zdroj
origin_imported_from: ""

# Dátum importu
origin_import_date: ""

# 🧱 RESERVED ---------------------------------------------------------

fm_reserved1: ""
fm_reserved2: ""
---

<!-- SDLC_INSTANCE_ID: PRJ-PENDING-GestureGlove -->

# 03. Technologies

Použité technológie, platformy, nástroje a ich verzie.

- Tech 1
- Tech 2

[↩️ Späť](../index.md)

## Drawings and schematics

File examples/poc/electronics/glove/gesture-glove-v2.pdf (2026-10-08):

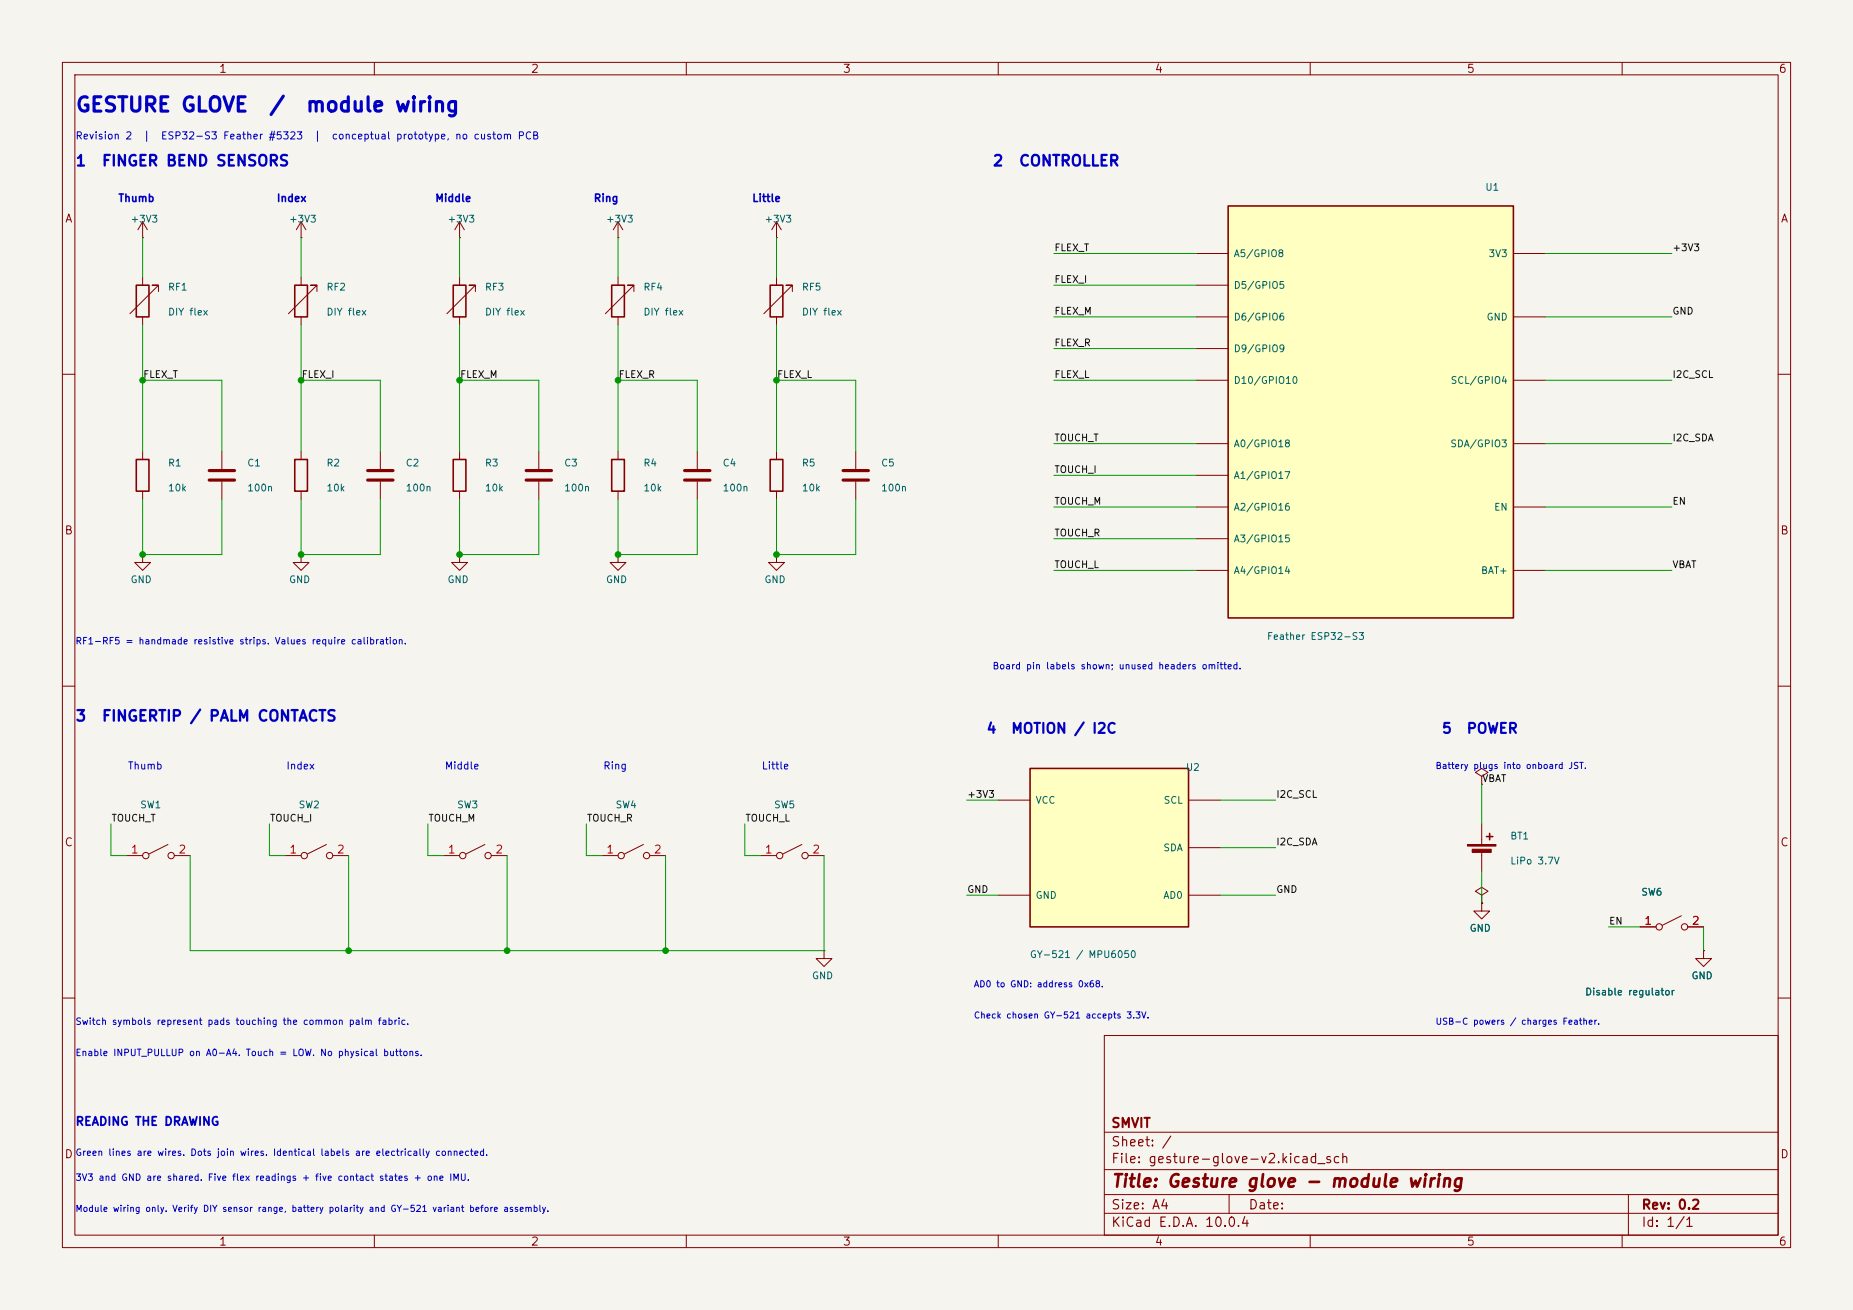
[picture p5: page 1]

Little GESTURE GLOVE / module wiring

Revision 2 | ESP32-S3 Feather #5323 | conceptual prototype, no custom PCB
Index 1 FINGER BEND SENSORS

TOUCH_I Board pin labels shown; unused headers omitted.

RF1-RF5 = handmade resistive strips. Values require calibration. 3 FINGERTIP / PALM CONTACTS

Battery plugs into onboard JST.

Switch symbols represent pads touching the common palm fabric.

USB-C powers / charges Feather.

Enable INPUT_PULLUP on A0-A4. Touch = LOW. No physical buttons.

SMVIT
Sheet: /
File: gesture-glove-v2.kicad_sch
Title: Gesture glove - module wiring

Size: A4 | Rev: 0.2
KiCad E.D.A. 10.0.4 | Id: 1/1

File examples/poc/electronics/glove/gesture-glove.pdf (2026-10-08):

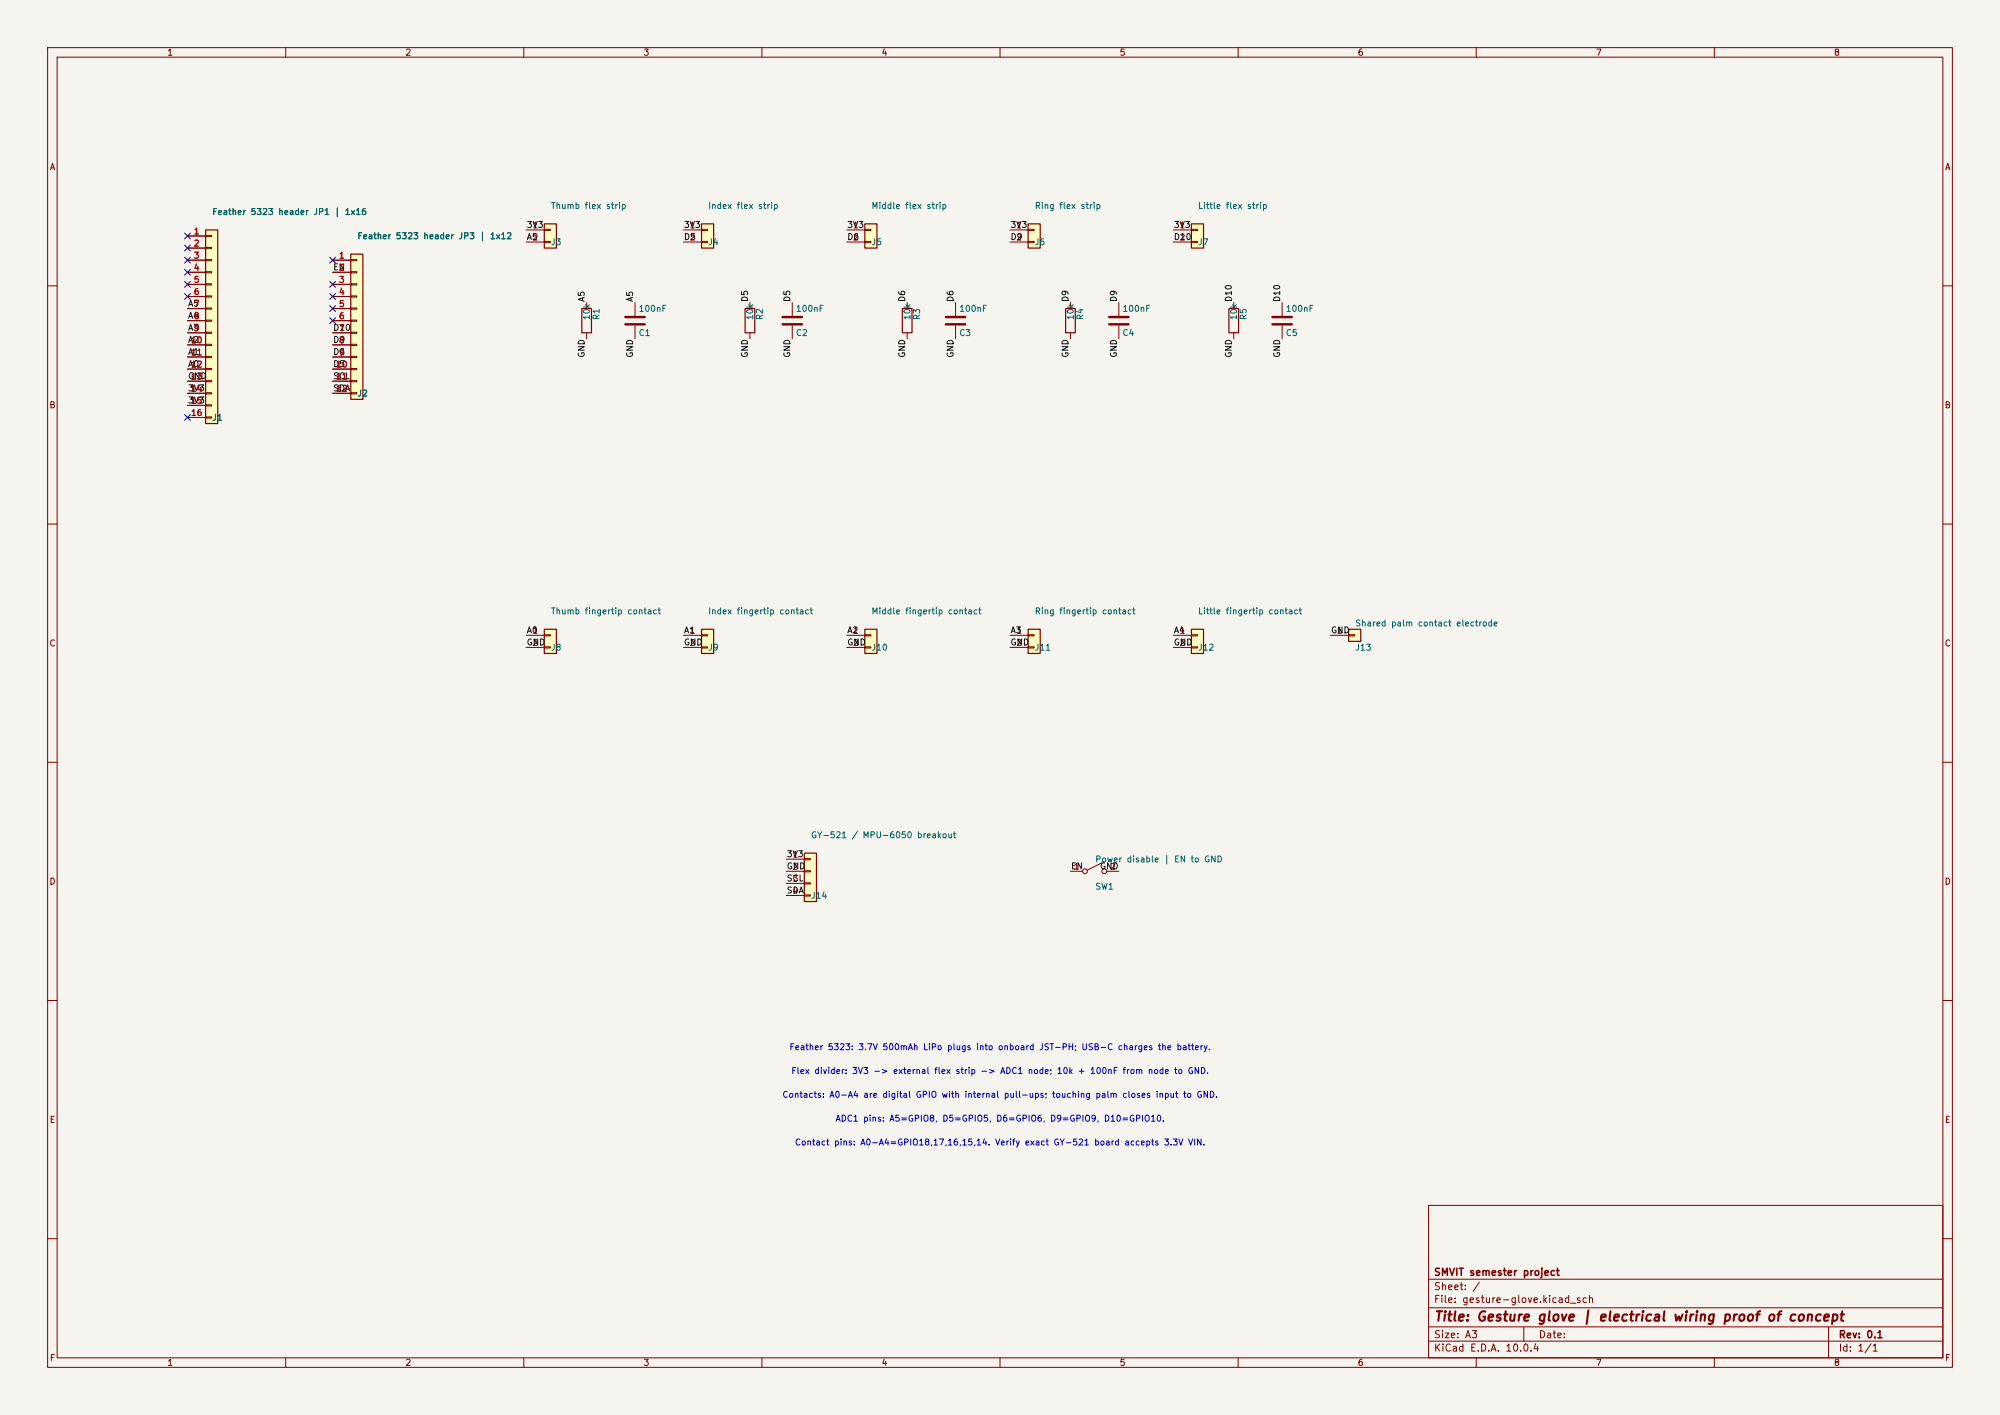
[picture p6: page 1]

Shared palm contact electrode 1

SW1 Power disable | EN to GND

ADC1 pins: A5=GPIO8, D5=GPIO5, D6=GPIO6, D9=GPIO9, D10=GPIO10. Feather 5323: 3.7V 500mAh LiPo plugs into onboard JST-PH; USB-C charges the battery. Flex divider: 3V3 -> external flex strip -> ADC1 node; 10k + 100nF from node to GND. Contacts: A0-A4 are digital GPIO with internal pull-ups; touching palm closes input to GND. Contact pins: A0-A4=GPIO18,17,16,15,14. Verify exact GY-521 board accepts 3.3V VIN.

SMVIT semester project
Sheet: /
File: gesture-glove.kicad_sch
Title: Gesture glove | electrical wiring proof of concept

Size: A3 | Rev: 0.1 | F Date:
KiCad E.D.A. 10.0.4 | Id: 1/1

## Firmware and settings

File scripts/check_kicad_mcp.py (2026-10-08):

"""Check the configured MCP against the open, disposable integration-test board."""
import asyncio
import json
import tomllib
from datetime import timedelta
from pathlib import Path

from mcp import ClientSession, StdioServerParameters
from mcp.client.stdio import stdio_client


async def main():
    root = Path(__file__).resolve().parents[1]
    config = tomllib.loads((root / ".codex/config.toml").read_text())["mcp_servers"]["kicad"]
    params = StdioServerParameters(command=config["command"], args=config["args"], cwd=Path.cwd())
    async with stdio_client(params) as (reader, writer):
        async with ClientSession(reader, writer, read_timeout_seconds=timedelta(seconds=60)) as session:
            await session.initialize()
            tools = await session.list_tools()
            print(f"MCP initialized: {len(tools.tools)} tools", flush=True)

            async def call(name, args=None):
                response = await session.call_tool(name, args or {})
                assert not response.isError, response
                payload = json.loads(next(p.text for p in response.content if p.type == "text"))
                print(name, json.dumps(payload), flush=True)
                assert not payload.get("error"), payload
                assert payload.get("success") is not False, payload
                return payload

            connection = await call("connect_to_kicad")
            assert connection.get("connected"), connection
            # Never run the edit test against a user's actual design.
            assert "integration-test.kicad_pcb" in connection["message"], connection
            await call("get_kicad_version")
            await call("get_layers")
            before = await call("get_tracks")
            transaction = await call("begin_commit")
            assert transaction.get("commit_id"), transaction
            created = None
            committed = False
            try:
                created = await call("place_track", {
                    "start_x_mm": 110, "start_y_mm": 115,
                    "end_x_mm": 130, "end_y_mm": 115,
                    "width_mm": 0.5, "layer": "F.Cu", "net_code": 0,
                })
                await call("end_commit", {"commit_id": transaction["commit_id"], "action": "commit",
                                          "message": "MCP integration check"})
                committed = True
                tracks = await call("get_tracks")
                assert tracks["count"] == before["count"] + 1
                assert any(t["id"] == created["track_id"] for t in tracks["tracks"])
            finally:
                if committed and created:
                    await call("delete_item", {"item_id": created["track_id"]})
                else:
                    await call("end_commit", {"commit_id": transaction["commit_id"], "action": "drop"})
            after = await call("get_tracks")
            assert after == before, "Cleanup did not restore the original tracks"
            print("Verified live read, track creation, and removal.", flush=True)


if __name__ == "__main__":
    asyncio.run(main())

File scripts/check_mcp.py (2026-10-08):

"""Exercise the same stdio command configured for Codex, optionally building the PoC."""
import argparse
import asyncio
import base64
import json
from datetime import timedelta
from pathlib import Path
import tomllib

from mcp import ClientSession, StdioServerParameters
from mcp.client.stdio import stdio_client


async def main(build_poc, capture):
    root = Path(__file__).resolve().parents[1]
    config = tomllib.loads((root / ".codex/config.toml").read_text())["mcp_servers"]["freecad"]
    params = StdioServerParameters(command=config["command"], args=config["args"], cwd=Path.cwd())
    async with stdio_client(params) as (reader, writer):
        async with ClientSession(reader, writer, read_timeout_seconds=timedelta(seconds=120)) as session:
            initialized = await session.initialize()
            tools = await session.list_tools()
            print(f"MCP initialized: {initialized.serverInfo.name}; {len(tools.tools)} tools", flush=True)

            async def call(name, arguments=None):
                response = await session.call_tool(name, arguments or {})
                messages = [part.text for part in response.content if part.type == "text"]
                for message in messages:
                    print(f"{name}: {message}", flush=True)
                    if message.startswith(("Failed to ", "Error ", "Error:")):
                        raise RuntimeError(message)
                if response.isError:
                    raise RuntimeError(f"{name} failed")
                # The upstream server also reports failures in text JSON payloads.
                for message in messages:
                    try:
                        payload = json.loads(message)
                    except json.JSONDecodeError:
                        continue
                    if isinstance(payload, dict) and payload.get("success") is False:
                        raise RuntimeError(f"{name} failed: {payload}")
                return response

            def json_payload(response):
                for part in response.content:
                    if part.type == "text":
                        try:
                            return json.loads(part.text)
                        except json.JSONDecodeError:
                            pass
                raise RuntimeError("Expected a JSON tool response")

            status = json_payload(await call("get_rpc_status"))
            if not status.get("success") or status.get("gui_dispatch", {}).get("state") != "healthy":
                raise RuntimeError(f"FreeCAD is not healthy: {status}")
            if not (build_poc or capture):
                await call("list_documents")
                return

            if build_poc:
                code = "project_root = " + repr(str(root)) + "\n"
                code += (root / "examples/poc/cad/glove_poc.py").read_text()
                await call("execute_code", {"code": code, "include_screenshot": False})
            # FreeCAD derives a new internal document name from the filename on
            # reopen, so discover it rather than assuming it remains GlovePoC.
            documents = json_payload(await call("list_documents"))
            matches = []
            for document_name in documents:
                board = json_payload(await call("get_object", {
                    "doc_name": document_name, "obj_name": "ESP32Board", "include_screenshot": False,
                }))
                if board is not None:
                    matches.append(document_name)
            if len(matches) != 1:
                raise RuntimeError("Open exactly one glove PoC document before capturing")
            await call("execute_code", {
                "code": (
                    f"App.setActiveDocument({matches[0]!r})\n"
                    "doc = App.ActiveDocument\n"
                    "assert len(doc.FlexSensors.Group) == 5\n"
                    "assert len(doc.Contacts.Group) == 6\n"
                    "assert abs(doc.ESP32Board.Length.Value - 50.8) < 0.001\n"
                    "assert abs(doc.ESP32Board.Width.Value - 22.86) < 0.001\n"
                    "assert all(o.Shape.isValid() for o in doc.Objects if hasattr(o, 'Shape'))\n"
                    "print('Verified board dimensions, five flex strips, five fingertip pads, palm contact, and valid geometry.')"
                ),
                "include_screenshot": False,
            })
            for view, filename in [("Isometric", "glove-poc.png"), ("Bottom", "glove-poc-palm.png")]:
                result = await call("get_view", {"view_name": view, "width": 1400, "height": 1100})
                images = [part for part in result.content if part.type == "image"]
                if not images:
                    raise RuntimeError(f"No screenshot returned for {view}")
                path = root / "examples/poc/cad" / filename
                path.write_bytes(base64.b64decode(images[0].data))
                print(f"Saved {path}")
            await call("execute_code", {
                "code": "Gui.activeDocument().activeView().viewAxonometric(); Gui.activeDocument().activeView().fitAll(); App.ActiveDocument.save()",
                "include_screenshot": False,
            })


if __name__ == "__main__":
    parser = argparse.ArgumentParser(description=__doc__)
    parser.add_argument("--build-poc", action="store_true", help="Create and save the glove placement model")
    parser.add_argument("--capture", action="store_true", help="Capture views of the open GlovePoC document")
    args = parser.parse_args()
    asyncio.run(main(args.build_poc, args.capture))

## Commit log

2026-10-08 Initialize from STHDF class template d30dd1d
    [20250815-KNIFES_with_SFIA.ods, KNIFE-OVERVIEW-ONLY-20250917.csv, KNIFE-OVERVIEW-ONLY-20250917.ods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]
2026-10-08 Add gesture glove course workspace and portable Nix CAD integrations
    [gesture-glove-v2.kicad_sch, gesture-glove.fzz, gesture-glove.kicad_sch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]
2026-10-08 Fix optional nixGL NVIDIA driver compatibility with nixpkgs 26.05
